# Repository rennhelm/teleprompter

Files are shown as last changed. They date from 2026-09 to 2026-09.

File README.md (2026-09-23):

# Teleprompter

A two-board DIY teleprompter for YouTube and classes: an ESP32-S3 display
board that renders and scrolls the script behind beamsplitter glass, and a
separate ESP32-S3 remote that controls speed, play/pause and re-pacing over
ESP-NOW.

## Repo layout

```
teleprompter/
├── teleprompter-display/   ESP32-S3-Touch-LCD-7B firmware (the actual teleprompter)
├── teleprompter-remote/    ESP32-S3-N16R8 DevKitC firmware (handheld remote)
├── docs/                   Design notes, build history, parts list
└── images/                 Photos / video of the build
```

`teleprompter-display/` and `teleprompter-remote/` are each a complete, independent PlatformIO project
— open either one directly in VS Code (File > Open Folder, the folder
containing its `platformio.ini`) and Build/Upload as normal. See each
project's config header (`src/tp_config.h`, `src/ctl_config.h`) for pins
and tunables.

## What this is

- **Display**: 1024x600 IPS touch display, custom scanline text renderer
  (no frame buffer — see `docs/renderer-rewrite.md`), mirror-flip for
  beamsplitter glass, Wi-Fi AP with a web page to paste/edit the script and
  adjust speed/brightness live, and a "target run length" mode that paces
  the scroll to finish a script in a set time (`docs/pacing-and-run-model.md`).
- **Remote**: three buttons (faster / slower / play-pause), talks to the
  display over ESP-NOW, status LED. See `docs/remote-controller.md`.

## Getting started

1. Read `docs/hardware-gotchas.md` first. It has the known-good
   `platformio.ini` settings and the toolchain fixes (Windows long-path
   limit, wrong PlatformIO platform version) that everything else depends on.
2. Build and flash `teleprompter-display/` first. Join the "Teleprompter"
   Wi-Fi network (password `teleprompter123`) and open `http://192.168.4.1/`
   to confirm the control page loads, before touching the remote.
3. `teleprompter-remote/README.md` covers remote wiring, controls and the
   status LED.

## Parts list

See `docs/Teleprompter_Parts.xlsx`.

## Design background

The `docs/` folder has the fuller story of *why* things are built this way,
including the dead ends (LVGL-based rendering, hardware mirror flip,
on-screen touch controls) so nobody re-walks them:

- `docs/architecture-plan.md` — overall hardware/software decisions and build phases
- `docs/renderer-rewrite.md` — why the display uses a custom scanline renderer instead of LVGL
- `docs/pacing-and-run-model.md` — the target-run-length / start-paused feature
- `docs/remote-controller.md` — remote hardware and the ESP-NOW protocol
- `docs/hardware-gotchas.md` — toolchain and hardware bring-up issues, in the order they were found

## License

See `LICENSE`.

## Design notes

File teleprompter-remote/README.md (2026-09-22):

# Teleprompter remote

ESP32-S3-N16R8 DevKitC, three buttons. Separate PlatformIO project from the
display; flash it to the second board.

## Wiring

Every button is two wires: pin to button, button to GND. Internal pull-ups are
enabled in firmware, so no resistors. Pin numbers live in `src/ctl_config.h`;
if you rewire, change them there and update this table.

| Signal | Pin |
| --- | --- |
| Faster | GPIO7 to GND |
| Slower | GPIO5 to GND |
| Play / pause | GPIO4 to GND |
| LED | GPIO48 (onboard addressable LED on most S3 DevKitC boards) |

Pins avoided on purpose: 0, 45, 46 (strapping), 19, 20 (USB), 26-32 (flash) and
33-37 (the octal PSRAM on an N16R8 part). Nothing here uses the ADC, so the
ADC1-only restriction that an analog control would have imposed does not apply.

## Controls

| Control | Action |
| --- | --- |
| Faster | +5% speed, repeats while held |
| Slower | -5% speed, repeats while held |
| Play | play / pause |
| Play, long (0.8 s) | back to top |
| Faster + Slower together | re-pace: recompute speed to land on the target time |

**Steps are relative, not a fixed px/s.** A "+5 px/s" step would be a 22% change
on a script paced at 23 px/s and a 2% change at 200 px/s, so it would feel
completely different depending on the script. A percentage feels the same
everywhere.

**The change sticks.** Buttons have no spring return, so a speed you press in
stays until you press again. That means the paced speed does drift away from the
target as you use it, which is what the display's drift readout is for, and what
the re-pace chord is for: it recomputes the speed from the distance left over
the time left, putting you back on schedule from wherever you are.

Holding a speed button repeats about six times a second after a half second
delay, so roughly a second of holding is a 1.34x change. Fine adjustment by
tapping, big changes by holding.

## LED

| Colour | Meaning |
| --- | --- |
| Red | no link to the display |
| Amber | paused |
| Green | playing |
| Blue | run finished |
| White flash | command sent |
| Blinking | more than 3 s off the target time |

The blink is the useful one: it tells you to lean on the slower or faster button
without having to look away from the script.

## Setup notes

- `CTL_CHANNEL` must match `TP_AP_CHANNEL` in the display's `tp_config.h`. Both
  are 1. ESP-NOW needs both ends on the same channel and there is no
  negotiation.
- `src/tp_link.h` is a **copy of the display's file**. If you change the
  protocol, copy it across again rather than editing one side.
- Re-pace only does anything when a target length is set on the display. Without
  one there is no schedule to get back onto.

## Tuning the feel

All in `ctl_config.h`:

- `CTL_STEP` (0.05): how much one press moves the speed.
- `CTL_REPEAT_DELAY_MS` (500) and `CTL_REPEAT_MS` (150): how quickly holding a
  button starts and then continues repeating.
- `CTL_LONG_PRESS_MS` (800): how long a hold on Play means back-to-top.

## No link?

The remote prints its MAC and channel at boot, and the display logs
`ESP-NOW listening on channel 1` plus the remote's MAC the first time it hears
from it. If the display never logs the remote, the channel is the first thing to
check. The remote pings once a second when idle, so the display always knows
where to send its status replies even if it reboots mid-session.

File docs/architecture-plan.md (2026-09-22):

# Teleprompter — Hardware Architecture Plan

## Goal
DIY teleprompter for YouTube and classes, built on two ESP32 boards.

## Components
- **Display unit:** Waveshare ESP32-S3-Touch-LCD-7B
  - 1024x600 IPS RGB display, 5-point capacitive touch
  - ESP32-S3, 16MB flash, 8MB PSRAM, dual-core LX7 up to 240MHz
  - Wi-Fi 2.4GHz b/g/n + BLE 5, onboard antennas
  - TF/SD card slot, USB-C (power + flashing), CAN/RS485/I2C headers, PH2.0 LiPo connector
  - Supports Arduino and ESP-IDF
  - Source: https://docs.waveshare.com/ESP32-S3-Touch-LCD-7B
- **Controller unit:** a second, separate ESP32 devkit (e.g. ESP32-C3/S3 mini)
  - Rotary encoder (scroll speed), buttons (play/pause, reverse/restart)
  - Battery powered (single-cell LiPo), handheld/pedal-style remote

## Key architecture decisions
- **Text entry → Wi-Fi**, not Bluetooth. Display board hosts its own small web
  server with a page to type/paste a script directly (originally planned as a
  file upload; switched to an in-browser textarea — simpler, and BLE file
  transfer was impractical for text anyway due to MTU limits).
- **Display Wi-Fi mode → AP (its own hotspot)**, not joining the home LAN.
  This pins the Wi-Fi channel, which avoids channel-sync headaches with
  ESP-NOW (see below). STA + mDNS ("teleprompter.local") can be added later
  once the core works.
- **Scroll control → ESP-NOW**, not classic Wi-Fi or BLE, for the
  controller-to-display link. Peer-to-peer, no pairing ceremony, low enough
  latency that a physical speed knob feels instant. Message = simple struct
  like `{command, value}` (play/pause, speed, reverse).
  **On-screen touchscreen controls were built, tested, then deliberately
  removed** because they competed with the display's own redraw for
  CPU/PSRAM bandwidth. That reason no longer applies under the current
  renderer (see below), but the decision stands on ergonomics: control
  belongs on the wireless remote, not on glass you are reading through.
  Hooks for the remote's receive callback: `tp_display_set_speed(float)` and
  `tp_display_set_paused(bool)`, or `tp_app_set_speed()` /
  `tp_app_set_paused()` / `tp_app_rewind()` to also persist the value and
  reflect it on the web page. Speed is signed, so reverse is a negative
  value with no other change.
  Touch hardware itself is still unused, but the *bring-up* sequence it used
  to perform is load-bearing for the display and is preserved in
  `tp_board_init()` — see hardware-gotchas.md and renderer-rewrite.md.
- **Storage:** LittleFS on the onboard 16MB flash (not the SD card) — the
  current script is saved to `/script.txt` and reloaded on boot. Speed,
  brightness and mirror state live in NVS.
- **Mirror-flip mode is a must-have**, not a nice-to-have — horizontal
  text mirroring is what makes this usable behind teleprompter beamsplitter
  glass. **Resolved in software.** The hardware-level `esp_lcd_panel_mirror()`
  route was a dead end (see hardware-gotchas.md). It is now baked in at
  rasterisation time, once per script, so it costs nothing while scrolling.
- **Rendering → own scanline renderer, not LVGL** (2026-09-14). LVGL remains
  linked only as a font container. See renderer-rewrite.md for the full
  reasoning; the short version is that any design which composes a
  full-screen frame in PSRAM on this board is bandwidth-bound, so the
  firmware composes nothing and generates pixels as they are scanned out.

## Build order (phased)
1. ✅ Bring up display board — flash factory demo, confirm LCD + touch work.
2. ✅ Static renderer — hardcoded text, word wrap, white-on-black, custom
   96pt font.
3. ✅ Mirror-flip.
4. ✅ Auto-scroll engine — smooth, adjustable-speed scrolling.
   **Closed 2026-09-14**: the residual stutter was fixed by replacing the
   renderer outright (renderer-rewrite.md), not by mitigating LVGL. User
   confirmed on hardware that the stutter is gone.
5. ✅ Wi-Fi script entry — AP + web page + textarea + LittleFS save/reload.
   Now applies live; no reboot on save.
6. Controller board — encoder + buttons, ESP-NOW sender. **Not started —
   this is the next milestone.**
7. Pair and tune — connect the two, tune speed mapping/encoder feel, test
   range. Not started.
8. Rig it — mirror glass, mount/stand, battery, enclosure. Not started.

## Current firmware state (display board, as of 2026-09-14)

**Working and confirmed on physical hardware.** Black background, white
word-wrapped text in a custom 96pt Roboto font, optionally mirrored for
beamsplitter glass, auto-scrolling at an adjustable speed, with no stutter.

Rendering is a custom scanline renderer: the RGB panel runs in ESP-IDF's
no-frame-buffer mode and the script is rasterised once into a rolling 4bpp
alpha mask in PSRAM, which the panel's bounce-buffer callback expands
through a lookup table as the pixels are scanned out. Scroll position
advances inside that callback from `esp_timer_get_time()`, so it cannot be
stalled by Wi-Fi, HTTP, flash writes, or anything else running on the chip.
Full reasoning, measurements and verification notes: **renderer-rewrite.md**.

Wi-Fi AP ("Teleprompter" / "teleprompter123") serves a control page at
`http://192.168.4.1/`: script textarea, scroll speed, brightness, mirror
toggle, pause and back-to-top, all applied live.

Project layout:
- `lib/lvgl/` + `lib/lv_conf.h` — LVGL v8.4.0, sibling layout required by
  LVGL's internal includes. Used only for `lv_font_get_glyph_dsc()` and
  `lv_font_get_glyph_bitmap()`; `lv_init()` is never called.
- `src/` — `tp_config.h` (all tunables), `tp_board.cpp` (I2C IO expander:
  backlight, brightness, power-up sequence), `tp_text.cpp` (layout +
  rasterisation), `tp_display.cpp` (panel + scanline renderer + scroll
  clock), `tp_web.cpp` (AP + control page), `main.cpp`, `Roboto_96.c`.
- All Waveshare vendor driver files (`rgb_lcd_port`, `gt911`/`touch`,
  `io_extension`, `i2c`, `esp_lv_adapter_arduino`) have been **deleted**,
  along with all `[DIAG]` instrumentation.

## Headroom now available

Removing the frame buffers freed roughly 2.4 MB of PSRAM (the mask ring uses
2 MB of it), and scanline generation costs about 25% of one core on core 1,
with core 0 essentially idle apart from Wi-Fi. Features that were previously
rejected as too expensive should be re-evaluated against this budget rather
than against the old LVGL numbers.

## Next up
1. **Controller board (Phase 6)**: encoder + buttons, ESP-NOW sender. The
   display-side hooks are already in place (see decisions above).
2. Pair controller with display, tune scroll-speed mapping and encoder
   feel, test range (Phase 7).
3. Recording-workflow polish on the display side — start-paused/lead-in,
   position indicator, adjustable font size. Cheap now; see headroom above.
4. Rig it: mirror glass, mount/stand, battery, enclosure (Phase 8).

## Closed items (do not re-open)
- Scrolling stutter/flicker — closed by the renderer rewrite. The old
  "mitigate or accept the platform quirk" decision in this file is moot.
- `'0'` rendering as `'1'` — an LVGL cmap off-by-one plus a font generated
  without a zero. Fixed in `font_has()` and by regenerating `Roboto_96.c`.
  See renderer-rewrite.md.
- `ESP.restart()` on script save — gone, which also retires the observed
  Octal-PSRAM soft-reset watchdog quirk.

See `hardware-gotchas.md` for the known-good `platformio.ini`, every
toolchain fix, and the detailed history of the mirror-flip, performance,
memory, and backlight/touch-init investigations. See `renderer-rewrite.md`
for the current rendering architecture.

> Note (repo docs pass): this file is the original planning doc and predates
> the remote controller build. It still describes the controller as
> "not started" with an encoder — see `remote-controller.md` for what was
> actually built (three buttons, no encoder). The remote's project folder is
> `teleprompter-remote/`, not `controller/`.

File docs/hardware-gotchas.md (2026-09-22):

# Teleprompter — Hardware Gotchas (ESP32-S3-Touch-LCD-7B)

Hard-won fixes, worth checking before re-diagnosing from scratch.

## UART1 / UART2 switch must match the USB-C port in use
The board has a physical switch selecting between two UART routings (UART1 /
UART2) to the onboard USB-C UART bridge (CH340, appears in Windows Device
Manager as "USB-Enhanced-SERIAL CH340"). If the switch position doesn't match
the port you're actually plugged into, you get a fully-enumerated COM port
that silently fails to talk to the chip — esptool reports:

```
A fatal error occurred: Failed to connect to ESP32-S3: No serial data received.
```

This looks identical to a bad cable, wrong driver, or boot-mode timing issue
(all of which we ruled out first) — check the switch position first.

## Reset button triggers a full POWERON reset, not just a chip reset
Pressing the physical RESET button on this board shows up in the Serial log
as `rst:0x1 (POWERON)` — the *same* reset-reason code as an actual power
cycle — rather than a simple reset-pin toggle (which normally shows up
differently, e.g. `RTC_SW_CPU_RST`). Seeing several `POWERON` resets in a
row during testing does **not** by itself mean the board's power supply is
failing — check whether the reset button was being pressed before chasing a
power-delivery theory (USB cable, port, hub, etc.).

## RTS-based auto-reset after flashing is not fully reliable on this board
esptool reports "Hard resetting via RTS pin..." at the end of a successful
upload. Early on this didn't actually restart the chip into the new firmware
and a manual press of the physical **RESET** button was needed — but this
became unnecessary once we moved to the pioarduino platform / newer esptool
(v5.3.0). If a flash ever seems to succeed but nothing happens on screen or
in the Serial Monitor, press RESET once before assuming something's wrong.

**Also note (2026-09-14):** running PlatformIO's "device monitor" task by
itself does **not** build or flash anything — it only opens the serial port
(which itself reboots the board via DTR/RTS toggling, producing a fresh
`POWERON` boot sequence that can look like a real reflash happened). If a
code change doesn't seem to take effect, confirm the *build/upload* task
actually ran (look for `Compiling ...` and `Writing at 0x...` in the output)
rather than assuming a "monitor" session proves the new code is running.

## Official PlatformIO `espressif32` platform is too old for Waveshare's demo code
Waveshare's example code (in their `ESP32-S3-Touch-LCD-7B` GitHub repo,
`Arduino/examples/` folder) uses `driver/i2c_master.h`, part of ESP-IDF's
newer I2C driver component. The official PlatformIO `espressif32` platform
bundles an older Arduino-ESP32 core that predates this header, causing:

```
fatal error: driver/i2c_master.h: No such file or directory
```

**Fix:** use the **pioarduino** community fork of the platform instead, which
tracks Espressif's current Arduino-ESP32 releases (3.3.x as of this writing,
built on a modern ESP-IDF that includes this driver):

```ini
platform = https://github.com/pioarduino/platform-espressif32/releases/download/stable/platform-espressif32.zip
```

This is a drop-in replacement — same board IDs, same workflow. Switching
platforms triggers a full toolchain re-download (several minutes, not a
hang).

## Windows long paths must be enabled before installing the pioarduino toolchain
The Arduino-ESP32 3.x libs package includes deeply-nested paths (from
Espressif's Matter/connectedhomeip code, for unrelated chip variants) that
exceed Windows' default 260-character path limit, failing with
`WindowsLongPathError`. Fix (one-time, needs a real Administrator PowerShell
— check the title bar literally says "Administrator", not just "run as
administrator" clicked from a non-elevated shell):

```powershell
New-ItemProperty -Path "HKLM:\SYSTEM\CurrentControlSet\Control\FileSystem" -Name "LongPathsEnabled" -Value 1 -PropertyType DWORD -Force
```

Requires a reboot to take effect.

## ESP_LOGI/ESP_LOGW output is silently suppressed by default
Arduino-ESP32's "Core Debug Level" defaults to a level that hides
`ESP_LOGI`/`ESP_LOGW` calls entirely — they just never show up in the Serial
Monitor, with no error. Fix: add `-DCORE_DEBUG_LEVEL=3` to `build_flags`.
Must go in the *same* `build_flags =` block as any other flags — a second,
separate `build_flags =` line causes `InvalidProjectConfError` (duplicate
key).

**Important addendum (2026-09-14) — this fix only works in files that
`#include <Arduino.h>`.** `CORE_DEBUG_LEVEL` only affects `ESP_LOGx` output
in translation units where `Arduino.h` (which pulls in
`esp32-hal-log.h`, the shim that redefines `ESP_LOGx` to route through
Arduino's own formatted logger) is actually included, directly or
transitively. Two of this project's vendor files —
`rgb_lcd_port.cpp` and `esp_lv_adapter_arduino.cpp` — only include raw
ESP-IDF headers and never pull in `Arduino.h`. Their `ESP_LOGx` calls
(including a pre-existing, unconditional `ESP_LOGI(TAG, "Create LVGL
task")` in `esp_lv_adapter_init()` that runs every boot) have **never**
produced any visible Serial output, in any log captured across this whole
project — confirmed to be unrelated to log *level*, since explicitly adding
`esp_log_level_set("*", ESP_LOG_INFO)` as the very first line of `setup()`
(confirmed via the edit shifting `main.cpp`'s own log line numbers by
exactly 1, so the rebuild definitely took effect) still produced zero
output from either file. The actual mechanism wasn't fully pinned down
before this investigation paused, but is most likely a compile-time
`LOG_LOCAL_LEVEL` bound specific to translation units that never see the
Arduino shim, which a runtime `esp_log_level_set()` call cannot override.
**Workaround: use raw `printf()` instead of `ESP_LOGx` when instrumenting
`rgb_lcd_port.cpp` or `esp_lv_adapter_arduino.cpp` (or any other vendor file
that doesn't include `Arduino.h`).** `printf()` writes straight to the
console UART independent of the ESP-IDF/Arduino logging subsystem
entirely, and is confirmed as the reliable way to add diagnostics to these
two files.

## Known-good, confirmed-working `platformio.ini`
```ini
[env:esp32-s3-devkitc-1]
platform = https://github.com/pioarduino/platform-espressif32/releases/download/stable/platform-espressif32.zip
board = esp32-s3-devkitc-1
framework = arduino
monitor_speed = 115200
upload_port = COM4
monitor_port = COM4
upload_speed = 115200
board_build.arduino.memory_type = qio_opi
board_upload.flash_size = 16MB
board_build.partitions = default_16MB.csv
build_flags =
    -DBOARD_HAS_PSRAM
    -DCORE_DEBUG_LEVEL=3
```
(`qio_opi` = Quad I/O flash + Octal I/O PSRAM, correct for this board's
16MB flash / 8MB PSRAM ESP32-S3 module.)

## Display + touch bring-up (Waveshare's own demo, not hand-rolled)
Rather than writing our own RGB-LCD panel init (very finicky — pixel clock,
porches, sync pulses are panel-specific), we're building on top of
Waveshare's own vetted example instead:
- Source: `waveshareteam/ESP32-S3-Touch-LCD-7B` GitHub repo →
  `Arduino/examples/13_lvgl_v8_demo/`
- Driver files (`rgb_lcd_port`, `gt911`/`touch`, `io_extension`, `i2c`,
  `esp_lv_adapter_arduino`) copied into `src/`, left untouched.
- LVGL v8.4.0 + its `lv_conf.h` (from the repo's bundled
  `LVGL_v8.4.0.7z`) copied into `lib/lvgl/` and `lib/lv_conf.h`
  respectively — `lv_conf.h` must sit as a **sibling** of the `lvgl` folder,
  not inside it (LVGL's internal includes expect this relative layout).

**Confirmed working (2026-09-13):** compiled, flashed, and the stock LVGL
widgets demo (`lv_demo_widgets()`) renders on the physical screen with
working touch — full display + touch stack proven before writing any of our
own rendering code.

## RESOLVED: blank screen / no backlight after replacing the demo's setup() (2026-09-14)
**Symptom:** after swapping the stock demo's `setup()`/`loop()` for our own
teleprompter code (Wi-Fi AP, web-based script editor, sliding-window
scrolling canvas), the screen went completely black with **no backlight at
all** — not even a dim glow. This happened on every boot, including a clean
`POWERON` reset with zero errors or crashes in the serial log (confirmed via
diagnostic logging that setup() ran start to finish without issue). Multiple
false leads chased first: a suspected loose FPC ribbon cable (physical
inspection ruled this out), Wi-Fi/AP radio power draw or timing coinciding
with panel init (a real, plausible ESP32-S3 phenomenon, tested by
reordering init and by fully disabling Wi-Fi — screen stayed black either
way, ruling it out), and an unchecked `esp_lv_adapter_lock()` return value
(added logging — the lock was never actually failing).

**Actual root cause, found by diffing our `setup()` against the *original*
working demo's `setup()`:** two real bugs, both in code we hadn't touched
but had never actually run correctly:

1. `wavesahre_rgb_lcd_bl_on()` (in Waveshare's own `rgb_lcd_port.cpp`) is a
   **stub with the real hardware write commented out**:
   ```cpp
   void wavesahre_rgb_lcd_bl_on()
   {
       // IO EXTENSION_io_output(IO EXTENSION_IO_2, 1);  // Backlight ON configuration
   }
   ```
   The commented line doesn't even use real function/identifier names
   (`IO EXTENSION_io_output` isn't a thing — the real function is
   `IO_EXTENSION_Output`). This is a placeholder Waveshare left unfinished in
   their own example. Calling it did nothing.

2. **`touch_gt911_init()` was never called.** The stock demo's `setup()`
   calls it *before* `waveshare_esp32_s3_rgb_lcd_init()`:
   ```cpp
   tp_handle = touch_gt911_init();
   panel_handle = waveshare_esp32_s3_rgb_lcd_init();
   wavesahre_rgb_lcd_bl_on();
   ```
   `touch_gt911_init()` is what actually brings up the I2C bus and the
   IO_EXTENSION GPIO expander chip that the backlight (`IO_EXTENSION_IO_2`),
   touch reset (`IO_EXTENSION_IO_1`), and **LCD reset**
   (`IO_EXTENSION_IO_3`) are all wired through — `EXAMPLE_PIN_NUM_BK_LIGHT`
   is `-1` in `rgb_lcd_port.h` precisely because backlight isn't a direct
   ESP32 GPIO. When we trimmed the demo's `setup()` down for our own use, we
   dropped the touch controller entirely (we don't need touch — see the
   on-screen-controls-removed decision below) and, with it, this
   load-bearing init call. Without it, nothing downstream (backlight, and
   likely the panel's own reset line) ever gets brought out of its power-on
   state, regardless of what the panel/LVGL code does afterward — hence a
   totally clean, crash-free boot with a permanently black screen.

**Fix applied:**
- `waveshare_esp32_s3_rgb_lcd_init()` now calls `DEV_I2C_Init()` (guarded —
  only if the I2C bus isn't already up) and `IO_EXTENSION_Init()` itself, as
  a safety net.
- `wavesahre_rgb_lcd_bl_on()` / `_bl_off()` now actually call
  `IO_EXTENSION_Output(IO_EXTENSION_IO_2, ...)`.
- `setup()` calls `touch_gt911_init()` before
  `waveshare_esp32_s3_rgb_lcd_init()`, exactly matching the proven-working
  demo's order, and passes the resulting `tp_handle` into
  `esp_lv_adapter_init()` instead of `NULL`. We still don't use touch
  functionality (on-screen controls were deliberately removed — see
  architecture-plan.md), but the init call itself is load-bearing for the
  display, not just for touch.

**Lesson for next time:** when a hand-rolled `setup()` diverges from a
vendor demo that's *known* to work on the same hardware, and the failure is
silent (no crash, no error) rather than a crash/assert, diff against the
original demo's init call order line-by-line rather than auditing the new
application logic — the bug can easily be a dropped call that looked
irrelevant (like touch init) rather than anything in the code that was
actually being suspected.

## Mirror-flip: `esp_lcd_panel_mirror()` is a dead end under this board's default render mode
Waveshare's `esp_lv_adapter_arduino` port has three "avoid tearing" modes,
set via `LVGL_PORT_AVOID_TEAR_MODE` in `esp_lv_adapter_arduino.h`:
- Mode 1: double-buffer + full-refresh (redraws the *entire* screen every
  frame)
- Mode 2: triple-buffer + full-refresh
- Mode 3: double-buffer + "direct mode" (**the vendor's default**) — LVGL
  writes straight into the panel's own physical frame buffer

Under mode 3, `esp_lcd_panel_mirror(panel_handle, true, false)` returns
`ESP_OK` but has **no visible effect**, because direct mode bypasses the
`esp_lcd_panel_draw_bitmap()` call where that mirror flag would normally be
honored. Switching to mode 1 does route through that path, but mode 1's
full-screen-every-frame redraw was far too slow on this hardware (PSRAM
bandwidth bound) to be usable. **Don't chase this further** — the working
fix is a software-level pre-mirror instead (next entry), which needs no
render-mode change at all.

## Mirror-flip: working approach — pre-mirror once into an off-screen canvas
Render the script text once into an `lv_canvas` (an off-screen pixel
buffer), flip that buffer's pixels horizontally exactly once (for a
`LV_IMG_CF_TRUE_COLOR` buffer this is a simple per-row swap:
`row[x] ↔ row[w-1-x]`), then scroll the canvas object like any normal
widget. Because the mirror only runs once at creation/refill time — never
per animation frame — it costs nothing while scrolling. Any buttons/sliders
should stay as separate, non-canvas objects so they render normally
(correct, since those are read directly, not through the beamsplitter
glass).

## `lv_canvas` buffer-size macros: use LVGL's own macro, don't hand-compute the stride
Learned the hard way, twice, while trying a memory-saving 1-bit format:
`LV_CANVAS_BUF_SIZE_ALPHA_1BIT(w, h)` (and the sibling indexed/alpha macros)
use a row stride of `(w >> 3) + 1` bytes — **not** the more "obvious"
`(w + 7) / 8`. Getting this wrong causes silently corrupted/blank canvas
content with **no crash**, and a related second bug: if a hand-rolled
scratch buffer for mirroring is sized off the wrong (smaller) stride, it
overflows and triggers `Stack smashing protect failure!` on return. Always
pull the real per-row size from LVGL's own macro and size any scratch
buffers from that same number. (`LV_IMG_CF_TRUE_COLOR` has no such trap —
its stride is just `w * sizeof(pixel)`.)

## `LV_IMG_CF_ALPHA_1BIT` + `img_recolor` styling: tried, abandoned as unreliable
To fit a long script's rendered image into available PSRAM, tried switching
the mirror canvas from full RGB565 color (2 bytes/pixel) to a 1-bit alpha
mask (16x smaller) plus `lv_obj_set_style_img_recolor()` /
`_recolor_opa()` to paint the mask white. After fixing the stride bug above,
it stopped crashing, but **never actually rendered any visible content** —
confirmed via a pixel-count diagnostic that the buffer genuinely contained
correctly-drawn glyph data, yet nothing appeared on screen. Root cause not
found. **Went back to `LV_IMG_CF_TRUE_COLOR`** (the format proven to work)
and solved the memory problem a different way instead (next entry) rather
than continuing to debug this blind.

## Long-script memory problem: use a small sliding window, not one giant pre-rendered image
Pre-rendering the *entire* script as one full-color image doesn't scale — a
590-byte test script alone wraps to ~2987px tall, needing ~5.8MB as a
`LV_IMG_CF_TRUE_COLOR` canvas, more than the ~4.4MB of PSRAM actually free
after the display's own frame buffers and other allocations. A real script
would only be worse.

**Fix:** allocate one small, **fixed-size** canvas (2 screen-heights tall —
independent of script length) and treat it as a window sliding through the
full script's virtual height. The key trick: `lv_canvas_draw_text()` will
happily draw starting from a *negative* Y coordinate and clip everything
above the canvas automatically, so "render the slice starting N pixels into
the document" is just `lv_canvas_draw_text(canvas, 0, -N, ..., full_script)`
— no manual line-break/pagination bookkeeping needed, LVGL's own word-wrap
does it every time. Refill (clear, redraw, re-mirror) only when the visible
viewport gets within one screen-height of the edge of what's currently
rendered — at typical scroll speeds that's roughly once every several
seconds, cheap enough not to affect frame rate.

Status: position math and buffer content both verified correct via
diagnostic logging, and — as of the backlight/touch-init fix above — now
confirmed actually rendering on the physical display too.

### Useful diagnostic pattern for "is it a position bug or a content bug?"
When something won't show up on screen, add periodic logging of the actual
state (`lv_obj_get_y()`, a manual pixel-count scan of the canvas buffer for
non-zero values) rather than re-reading the code blind. This cleanly
separated "the scroll math is right and the buffer genuinely has drawn
content in it" from "but nothing reaches the physical screen" in one round,
instead of several more rounds of guessing.

## RESOLVED (root cause identified 2026-09-14): scrolling flicker/choppiness — LVGL's own render+flush cost climbs to ~300ms+ under continuous scrolling

**Symptom:** user-reported "flicker, makes it hard to read" while scrolling.

**Real fixes made along the way (confirmed via log evidence, worth keeping
regardless of the root-cause finding below):**
1. `lv_canvas_fill_bg()` cost ~768,000us per call. Replaced with a direct
   `memset()` (fill color is always solid black = all-zero bytes on
   RGB565) — now ~207,000-320,000us, matching a raw PSRAM memset benchmark
   of the same buffer size. The remaining cost is genuine PSRAM bus
   contention from the RGB panel's continuous framebuffer DMA (confirmed
   via an early pre-panel-init vs. post-panel-init memset benchmark showing
   a 3-4.4x slowdown once the panel starts driving the display), not
   further software inefficiency.
2. `g_window_height` was `screen_height * 2`, which worked out to *zero*
   effective refill margin (the trigger math landed exactly at the
   threshold), causing back-to-back refills instead of the intended ~8s
   spacing. Changed to `* 3`; log-confirmed refill spacing now matches
   predicted math for the test script.
3. `scroll_timer_cb()` originally advanced the scroll position by a
   **fixed** per-tick amount regardless of actual elapsed time — silently
   cutting the real average scroll speed to roughly 1/10th of the
   configured px/sec once it became clear ticks were actually arriving
   every ~300ms+ instead of the intended ~33ms. Fixed to scale the step by
   real elapsed time (`gap_ms`) instead of assuming a fixed period.
4. Added a guard to skip a wasted "refill an already-blank window" event
   that happened right before wrap-to-top, when the test script (1066px)
   was shorter than the (now larger) render window (1800px). **Not yet
   independently re-verified with a dedicated log** — present in the
   flashed firmware but its effect hasn't specifically been confirmed.

**Diagnostic method:** added `g_max_tick_gap_ms` to `main.cpp` (actual
elapsed time between `scroll_timer_cb()` firings, via `millis()`), which
consistently settled around ~306-320ms during normal scrolling (vs. the
intended ~33ms), with spikes to ~950-1040ms lining up with
`refill_window()` calls. To find out *why*, added `printf()`-based
instrumentation (see the `ESP_LOGI/ESP_LOGW` gotcha above for why `printf`
and not `ESP_LOGx`) directly inside the vendor `esp_lv_adapter_arduino.cpp`,
measuring three things separately: (a) `flush_callback()`'s
`ulTaskNotifyTake()` vsync-wait time, (b) `lv_timer_handler()`'s own total
execution time per call, and (c) the full `lvgl_port_task` loop iteration
time.

**Findings, definitive:**
- **Ruled out: Wi-Fi/AP/webserver polling.** Direct paired A/B test
  (`ENABLE_WIFI=1` vs. `0`) showed statistically identical
  `max_tick_gap_ms` in both; only `free_heap` differed.
- **Ruled out: the RGB panel's own vsync timing, and the `flush_callback()`
  blocking-wait theory.** The instrumented vsync wait stayed a steady
  ~23-30ms throughout, matching the calculated panel refresh rate
  (`EXAMPLE_LCD_PIXEL_CLOCK_HZ` + porch/pulse-width constants ≈ 32.75Hz ≈
  30.5ms/frame) almost exactly. This is the *opposite* of the ~300ms
  anomaly, so the flush-blocking mechanism is not the cause.
- **Ruled out: task-scheduling/`vTaskDelay` slippage.** `task_delay_ms`
  (what `lv_timer_handler()` asks the task to sleep) was always `0`
  (clamped up to the 10ms floor) — the loop is not waiting on anything
  external to `lv_timer_handler()` itself.
- **Confirmed root cause: `lv_timer_handler()`'s own execution time climbs
  over time, independent of refills, until it plateaus around the observed
  ~295-320ms** — e.g. one capture showed it climb steadily across roughly
  10-15 seconds (119ms → 173ms → 234ms → 295ms) then hold there, tracking
  `max_tick_gap_ms` almost exactly. This is the actual rendering/flush cost
  of moving our canvas each tick — not a blocked wait, not a scheduling
  gap, just genuinely slow.

**This is almost certainly the same phenomenon as the "periodic ~2-minute
redraw slowdown" entry above** (a documented, unresolved community report —
suspected PSRAM cache-coherency mismatch between the Arduino-ESP32 core and
Octal PSRAM burst behavior), just captured here with much finer
granularity via direct instrumentation rather than coarse tick-interval
sampling. Both entries should be read together; they're very likely one
underlying platform limitation, not two separate bugs. See the same two
reference links there.

**Practical takeaway:** the ~300ms+ stall is not fixable by anything in our
own `main.cpp` scroll/render logic (already-fixed items 1-4 above were
worthwhile independently, but don't touch this), and multiple external
reports treat the underlying cause as an unresolved platform/core
limitation rather than something fixable from application code. **Decision
point, not yet made:** whether to (a) look for an application-level
mitigation that reduces how much area gets re-flushed per tick (e.g.
smaller per-tick invalidation), accepting this is a mitigation and not a
fix, or (b) accept this as a documented platform quirk, same as the
2-minute-oscillation entry above, and move on to the remaining build
phases (controller board, ESP-NOW, enclosure). Revisit this decision before
doing any further internals-level work here — don't restart the
investigation from scratch.

**Diagnostics left in place:** `main.cpp` still has
`g_max_tick_gap_ms`/`diagnostics_timer_cb()`, and
`esp_lv_adapter_arduino.cpp` still has the `printf()`-based `[DIAG]`
instrumentation described above (three checkpoints: entry of
`esp_lv_adapter_init()`, entry of `lvgl_port_task()`'s loop, and a
100-iteration heartbeat plus new-max-only prints for the three measured
timings). Safe to leave in — cheap when nothing new happens — but worth
removing once this is fully closed out, since the `[DIAG]`-prefixed lines
add serial noise.

## Possible ESP32-S3 Octal-PSRAM soft-reset quirk after Wi-Fi save-and-restart (watch for recurrence)
While diagnosing the blank-screen issue above, one boot (following the
web UI's "Save and Restart", which calls `ESP.restart()` right after a
PSRAM-heavy canvas allocation) came up with `rst:0x10 (RTCWDT_RTC_RST)` — a
watchdog reset — and hung right after the "Script wraps..." log line before
finishing setup. This didn't reproduce on every save+restart cycle, so it
wasn't chased further, but it matches a known ESP32-S3 erratum where Octal
PSRAM doesn't always reinitialize cleanly after a *soft* reset
(`esp_restart()`), only after a real power cycle. If this recurs
consistently, the fix is likely avoiding `ESP.restart()` after heavy PSRAM
use (or forcing a harder reset), not a code bug in our sketch.

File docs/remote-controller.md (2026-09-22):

# Teleprompter — Remote controller (Phase 6, 2026-09-15)

Second board: ESP32-S3-N16R8 DevKitC. **Three buttons**: faster, slower,
play/pause. Separate PlatformIO project in `teleprompter-remote/` (earlier planning
notes called it `controller/`).

A joystick version was built first and then dropped in favour of buttons. The
reasoning behind both is kept below, because the shape of the control determines
the command it should send and that is not obvious.

## The control shape decides the command

The protocol carries two ways to move the speed. Which one is correct depends
entirely on whether the control springs back by itself.

**Buttons → `TP_CMD_SPEED_NUDGE`** (what is built). Scales the base speed by a
relative amount, and the change **sticks**:

```
base *= (1 + value / 1000)
```

Relative, not absolute, on purpose: a fixed "+5 px/s" step is a 22% change at
23 px/s and a 2% change at 200 px/s, so it would feel completely different
depending on the script length. A percentage feels the same everywhere.

Because the change sticks, the paced speed does drift away from the target as
you use it. That is what the drift readout is for, and what re-pace is for.

**Spring-centred controls (joystick, slider) → `TP_CMD_SPEED_TRIM`** (in the
protocol, unused by this remote). Biases the base speed rather than replacing
it, `effective = base * (1 + trim)`, so letting go returns the scroll to exactly
the paced speed and the target can never be lost. A momentary trim also needs
the display-side failsafe that clears it if the remote goes quiet, so a flat
battery mid-deflection cannot leave the scroll stuck fast. That failsafe only
arms when a non-zero trim arrives, so the button remote never triggers it.

Base speed and trim stay separate variables on the display (`s_speed`, `s_trim`)
composed in one place (`apply_speed()` in `main.cpp`), so the web slider, the
duration target and the remote never fight over one value. `tp_app_repace()`
zeroes the trim, because "put me back on schedule" means from neutral.

## Control layout

| Control | Action |
| --- | --- |
| Faster (GPIO7) | +5%, repeats while held |
| Slower (GPIO5) | -5%, repeats while held |
| Play (GPIO4) | play / pause |
| Play, long 0.8 s | back to top |
| Faster + Slower together | re-pace |

The chord saves a fourth button for what is genuinely the most useful mid-take
control. One stray nudge fires before the chord is detected; harmless, because
re-pace recomputes the speed outright. Both buttons are then suppressed until
released so the chord does not ripple the speed.

All three buttons are pin-to-GND with internal pull-ups. **Nothing uses the ADC,
so the ADC1-only constraint below does not apply to the built remote.**

LED (onboard addressable, GPIO48): red = no link, amber = paused, green =
playing, blue = finished, white flash = command sent, blinking = more than 3 s
off the target. The blink is the useful one; it prompts a correction without
looking away from the script.

## Kept for reference: the ADC gotcha, if an analog control is ever added

An analog joystick or slider **must** be on ADC1, GPIO1-10. ADC2 shares hardware
with the Wi-Fi radio and reads on it fail whenever the radio is active, which on
this remote is always. It presents as a broken control, not as an error. Also:
VCC to 3V3, not 5V, or the ADC clips; and calibrate centre at boot by averaging,
because no real thumbstick sits at 2048.

Pins avoided throughout: 0/45/46 (strapping), 19/20 (USB), 26-32 (flash), 33-37
(octal PSRAM on an N16R8 part).

## Link details

- `CTL_CHANNEL` must equal `TP_AP_CHANNEL` (both 1). ESP-NOW has no channel
  negotiation, which is why the display's soft AP is pinned.
- The remote broadcasts; the display replies to whoever sent the command. The
  remote pings once a second when idle so the display always knows where to
  send status, even if the display reboots mid-session.
- `teleprompter-remote/src/tp_link.h` is a **copy** of the display's. Change one, copy it
  across; never edit one side only.
- Received commands are queued and applied on the display's own task, not in the
  Wi-Fi callback, because a rewind re-rasterises and would stall the Wi-Fi stack
  for a couple of hundred milliseconds.

## Also changed on the display side

- `tp_app_nudge_speed(factor)` added, floored at `TP_PACE_SPEED_MIN` rather than
  the slider's minimum, so a legitimately slow paced speed does not jump when
  nudged.
- `tp_app_set_speed()` and `tp_app_set_brightness()` no longer write NVS
  immediately; a repeating button would hammer flash. Flushed from `loop()` once
  settled.
- Status frames report the **effective** speed and compute drift from it.
- Web page shows "remote trim +25%" when a trim is applied, and uses the
  effective speed for its projections.

## Verification status

The button state machine was simulated on the host across five scenarios: a tap
gives exactly one step; a 1.2 s hold gives six steps (1.34x, matching the
documented figure); the chord gives one stray nudge then re-pace and nothing
further until release; a play tap gives only a toggle; a long play hold gives
only a rewind and no toggle on release. ESP-NOW callback signatures were checked
against `esp_now.h` for IDF 5.5 (note `esp_now_send_cb_t` changed shape in 5.4,
so no send callback is registered).

**Neither the remote firmware nor the display's nudge path has run on
hardware.** First check: the remote prints its MAC and channel at boot, and the
display logs the remote's MAC the first time it hears from it. If that line
never appears, check the channel.

> Note: this file is the design record. For current wiring and day-to-day use,
> `teleprompter-remote/README.md` is the operational reference, and
> `teleprompter-remote/src/ctl_config.h` is the source of truth for pins.

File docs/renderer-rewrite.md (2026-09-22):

# Teleprompter — Renderer rewrite (2026-09-14)

Closes the open decision in architecture-plan.md ("pursue an application-level
mitigation, or accept the ~300ms LVGL stall as a platform quirk"). **Neither.**
The third option was taking LVGL out of the render path entirely.

## Why the old approach could not be tuned into working

The earlier investigation was correct that `lv_timer_handler()` cost climbed to a
~300ms plateau, and correct that it wasn't vsync, Wi-Fi or scheduling. The
missing piece is *why* that ceiling exists, and it isn't a cache-coherency
erratum — it's arithmetic:

- The panel's own refresh DMA reads the 1.2 MB PSRAM frame buffer continuously,
  ~40 MB/s, whether or not anything changes. (With `bounce_buffer_size_px` set,
  that read is done by a CPU `memcpy` inside the DMA ISR, ~1960 interrupts/sec.)
- Scrolling a canvas means most of the screen is dirty every frame, so LVGL must
  re-blit ~614k pixels through its draw pipeline into PSRAM.
- ESP32-S3 PSRAM writes go through a **write-allocate** cache, so writing a frame
  costs a read *and* a write — roughly 2.4 MB of bus traffic per frame on top of
  the panel's own 40 MB/s.

Any design that composes a full-screen frame in PSRAM is bandwidth-bound on this
board. That is why mode 1 (full-refresh) was "too slow", why `lv_canvas_fill_bg`
was 768 ms, and why the raw `memset` benchmark only reached ~12 MB/s.

## What replaced it: generate scanlines, keep no frame buffer

The RGB panel now runs in ESP-IDF's no-frame-buffer mode
(`esp_lcd_rgb_panel_config_t.flags.no_fb = 1`, which **requires `num_fbs == 0`**).
In that mode the driver calls `on_bounce_empty(panel, buf, pos_px, len_bytes, ctx)`
to have the application fill each bounce buffer just before it is shifted out.

1. The script is rasterised **once** into a rolling 4-bits-per-pixel alpha mask in
   PSRAM (`TP_RING_ROWS` = 4096 rows x 512 bytes = 2 MB). Mirroring is baked in at
   rasterisation, never per frame.
2. The callback expands the 12 scanlines it is about to send straight from that
   mask through a 256-entry lookup table: one lookup and one aligned 32-bit store
   per two pixels.
3. Scroll position advances inside that callback from `esp_timer_get_time()`, in
   integer fixed point (no FPU in an ISR), latched once per frame at `pos_px == 0`.

Results by construction, not by tuning:
- PSRAM traffic per frame: ~2.4 MB → ~300 KB (mask reads only). Pixels are built
  in internal SRAM.
- Per-frame cost is **constant** — there is no periodic refill left to hitch on.
- Scrolling cannot be stalled by software. Wi-Fi, HTTP, flash writes and
  rasterising the next line all sit outside the render path.
- No tearing: pixels are generated as they are scanned out.
- Budget: ~1.8M cycles/frame of scanline generation ≈ 25% of one core, on core 1.
  Wi-Fi and the web server on core 0.

Fallback if `no_fb` ever misbehaves: `TP_USE_FRAMEBUFFER 1` in `tp_config.h`
switches to two PSRAM frame buffers filled by the same row-expansion code. Much
slower (~10-15 fps), but conventional, so it is a useful A/B.

## Silent bug found: LVGL resolves the codepoint just past a cmap range

`lv_font_get_glyph_dsc_id()` in LVGL 8 tests `rcp > range_length` rather than
`>=`. The single codepoint immediately after each cmap is therefore reported as
present and resolved to the **first glyph of the next range**.

`Roboto_96.c` was generated with `--symbols ...123456789...` — no `'0'` — and its
two ranges are 0x20-0x2F and 0x31-0x7E. So `'0'` (0x30) resolved to `'1'`:
**"2026" was rendering on screen as "2126"**, and every price and time was wrong,
with no error anywhere. Verified by host-rendering the real font.

Two fixes, both applied:
- `font_has()` in `tp_text.cpp` walks the cmaps itself, so a character the font
  lacks is always treated as missing rather than drawn as its neighbour.
- `src/Roboto_96.c` regenerated over 0x20-0x7E plus en/em dash, curly quotes and
  ellipsis, from the same Roboto variable font. Metrics are identical
  (`line_height` 103, `base_line` 23), and the `__has_include` header block is
  reproduced. To regenerate (e.g. a different size or typeface), with
  [lv_font_conv](https://github.com/lvgl/lv_font_conv) and a Roboto `.ttf`:

  ```
  npx lv_font_conv --bpp 4 --size 96 --no-compress --font roboto.ttf \
    -r 0x20-0x7E -r 0x2013-0x2014 -r 0x2018-0x2019 -r 0x201C-0x201D -r 0x2026 \
    --format lvgl -o src/Roboto_96.c
  ```

  Keep `0x20-0x7E` as one unbroken range. A gap is what caused the `'0'` bug.

## Gotchas from hardware-gotchas.md that are honoured in the new code

- **`ESP_LOGx` needs `Arduino.h` in the translation unit.** Every new source file
  includes it first, deliberately, with a comment saying why. Logging is visible
  this time; no `printf` workaround needed.
- **`touch_gt911_init()` was load-bearing for the display, not for touch.**
  `touch_gt911_init()` is gone, but `tp_board_init()` runs the same sequence in
  the same order before the panel: I2C up, expander mode register to all-outputs,
  then the GPIO4 / expander-IO1 reset dance with the same delays. LCD reset (IO3)
  high; backlight (IO2) explicitly low until 120 ms after the panel is scanning,
  so there is no garbage flash at boot. `tp_board_backlight()` really writes to
  the expander — it is not the vendor's commented-out stub.
- **`lib/lvgl/` + `lib/lv_conf.h` sibling layout** is unchanged. LVGL is now only
  a font container (`lv_font_get_glyph_dsc` / `lv_font_get_glyph_bitmap`).
  Nothing calls `lv_init()`, so its 48 KB pool is never allocated.
- **The Octal-PSRAM soft-reset quirk** can no longer be hit in normal use: saving
  a script re-lays out in place instead of calling `ESP.restart()`.
- Waveshare driver files deleted: `esp_lv_adapter_arduino.*`, `rgb_lcd_port.*`,
  `gt911.*`, `touch.*`, `i2c.*`, `io_extension.*`, along with all `[DIAG]`
  instrumentation.

## ESP-NOW hooks (Phase 6) are intact

`tp_display_set_speed(float)` and `tp_display_set_paused(bool)` are what the
remote's receive callback should call; `tp_app_set_speed()` / `tp_app_set_paused()`
/ `tp_app_rewind()` additionally persist and reflect on the web page. Speed is
signed, so reverse is a negative value with no other change. Wi-Fi stays in AP
mode, so the ESP-NOW channel is still pinned.

## Verification status

Host-compiled and rendered against real LVGL 8.4 font code and the actual font:
layout, word wrap, mid-word breaking, blank lines, glyph placement,
anti-aliasing, 4bpp mask packing, mirroring and the lookup-table expansion were
all checked as images. The ESP-IDF panel configuration was checked against
`esp_lcd_panel_rgb.h` / `.c` for IDF 5.5 (what pioarduino pulls in), in
particular that `no_fb` requires `num_fbs == 0`, that the frame-buffer size must
be a whole multiple of the bounce-buffer size (so `TP_BOUNCE_LINES` must divide
600), and the `on_bounce_empty` signature.

**Not yet flashed or run on the board.** First log lines to check:

```
I tp_display: scanline renderer active: no frame buffer, 12-line bounce buffers
I tp_text: laid out N lines, 115 px per line, ... rows per pass
I teleprompter: 32 fps | row ... | heap ... | psram ...
```

A steady ~32 fps with the row number climbing evenly is the fix working.
If bands of the screen tear or repeat under heavy Wi-Fi load, raise
`TP_BOUNCE_LINES` to 20 (costs 80 KB of internal RAM instead of 48 KB).

> Note (repo docs pass): "not yet flashed" above is as of this doc's original
> date (2026-09-14); architecture-plan.md's later changelog says the stutter
> fix was confirmed on hardware. Treat the verification note as historical.

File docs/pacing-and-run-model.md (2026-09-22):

# Teleprompter — Run model: target length and start-paused (2026-09-14)

Adds "set a target length and the script finishes in that time", plus booting
paused. Builds on the scanline renderer (see renderer-rewrite.md).

## The run model, and why the definition matters

A **run** is defined as: *first line sitting on the reading row* → *last line
sitting on the reading row*. The reading row is `TP_READ_LINE_Y` in
`tp_config.h`, default `V_RES / 3` = 200 px.

The useful consequence: the distance covered is exactly

```
travel = text_rows - line_height
```

which is **independent of where the reading row sits**. Moving the reading row
changes where the text rests on screen, not the timing. So:

```
speed_px_per_sec = travel / target_seconds
```

is the whole calculation. The start position is `-TP_READ_LINE_Y` (negative, so
there is blank above line one); `tp_text_row_ptr()` already returns null for
negative rows, so no special case was needed.

Any other definition of "finished" is materially wrong. If the run ended when
the last line scrolled off the *top*, the target would be overshot by one screen
height of travel — about 20% of a two minute run on a typical script — because
the speaker stops talking a screen-height before the text stops moving.

### Verified on host

`/tmp` harness rendered the frames at both extremes against the real font:
at the start position line one sits on the reading row with blank above; at the
end position the final line sits on that same row, earlier lines visible above
it for context, and **zero ink below it**. Numbers from the check: 25 lines,
69 words, text 2875 rows, travel 2760, so 2:00 → 23.0 px/s.

## Deliberately open loop

The target sets the **initial speed only**. The slider and the ESP-NOW hooks
still move it freely afterwards. There is no continuous auto-correction, on
purpose: a speed that creeps around while you are reading is horrible to read
from. Instead the control page shows the consequences and offers a manual fix:

- run clock `0:47 / 2:00`
- what the current speed projects to, and time left
- drift, "0:03 ahead" / "0:03 behind", once you have nudged the speed
- words per minute, flagged amber above 200 — the real sanity check, since a
  two minute target on a long script may imply an impossible reading rate
- **Re-pace**: recompute speed from distance left over time left

If continuous auto-pacing is ever wanted, it belongs behind a flag, not as the
default.

## Start paused, stop at end

- `TP_START_PAUSED` (default 1): boots parked with line one on the reading row.
  `s_paused` is initialised to this at file scope in `tp_display.cpp`, so there
  is no window between panel init and the first `set_paused()` call.
- `TP_STOP_AT_END` (default 1): the renderer pauses and latches `finished` when
  it reaches `end_row`, instead of looping. Reversing past `start_row` also
  stops. Set both to 0 for a continuously looping display.
- "Back to top" parks paused too — a rewind means "getting ready for a take".
- Play on a finished run rewinds first, and the page's button reads "Restart".

## Implementation notes

- **Run clock lives in the frame callback**, accumulated from the same `dt` the
  scroll position uses, so it measures scrolling rather than wall time and stops
  cleanly when paused. Kept as a 32-bit millisecond counter specifically so a
  task can read it without tearing against the interrupt that writes it (a
  64-bit microsecond counter could not be read atomically).
- **`apply_pacing()` is re-run on every layout change** — new script, mirror
  toggle — which is the real value of the feature: paste a longer script and the
  target holds, the scroll just slows down.
- `reload()` rewinds *before* re-laying out so the mask top-up task is not
  chasing a target derived from the old script, then rewinds again once the new
  range is known.
- Word count is a separate byte-wise pass (UTF-8 continuation bytes are all
  >= 0x80, so they can never be mistaken for whitespace). The layout loop itself
  rescans characters on line breaks, so counting inside it would double-count.
- New API: `tp_display_set_range()`, `tp_display_start_row()`,
  `tp_display_end_row()`, `tp_display_finished()`, `tp_display_run_ms()`,
  `tp_text_rows()`, `tp_text_word_count()`, `tp_app_set_duration()`,
  `tp_app_repace()`.
- NVS key `duration` (seconds, 0 = off) alongside `speed`, `mirror`, `bright`.

## Control page verified in a browser

The page was rendered headless against mock state at 400 px and 760 px wide:
no JS errors, and the arithmetic checked by hand against the mock (0:47 of 2:00,
1:16 left, 3 s behind, 35 wpm, progress bar at 37%). The firmware side of this
change has **not** been run on the board.

## Note for the ESP-NOW remote (Phase 6)

The run model gives the remote more to work with than play/pause/speed:
`tp_display_finished()` and `tp_display_run_ms()` are worth surfacing on the
handheld, and `tp_app_repace()` is a good candidate for a physical button —
"put me back on schedule" is a more useful control mid-take than nudging speed
by hand.

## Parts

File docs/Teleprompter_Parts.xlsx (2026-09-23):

Part | Price | Unit Price | DigiKey # | Qty. | Link
Waveshare ESP32-S3-Touch-LCD-7B | $54.99 | $54.99 | - | 1 | Link (https://www.amazon.com/dp/B0FDQXKFJ5?ref=ppx_yo2ov_dt_b_fed_asin_title)
ESP32-S3-N16R8 | $18.99 | $6.33 | - | 1 | Link (https://www.amazon.com/dp/B0F5QCK6X5?ref=ppx_yo2ov_dt_b_fed_asin_title&th=1)
Tactile Buttons (6X6X8) | $8.99 | $0.05 | - | 3 | Link (https://www.amazon.com/dp/B07ZBHXBZ4?ref=ppx_yo2ov_dt_b_fed_asin_title)
2.54mm Female Pin Connector (1X6) | $12.95 | $0.10 | - | 4 | Link (https://www.amazon.com/dp/B0GLHJ3DXH?ref=ppx_yo2ov_dt_b_fed_asin_title)
22 AWG Solid Core Tinned Copper Wire | $16.19 | $16.19 | - | 1 | Link (https://www.amazon.com/dp/B07TX6BX47?ref=ppx_yo2ov_dt_b_fed_asin_title&th=1)
Pololu S7V8F3 | $9.95 | $9.95 | 2183-2122-ND | 1 | Link (https://www.digikey.com/en/products/detail/pololu/2122/10451140?s=N4IgTCBcDaIAoHsA2yCuACMBGMEC6AvkA)
PCB Prototype Board | $7.99 | $0.25 | - | 2 | Link (https://www.amazon.com/dp/B0DBZ1BXFZ?ref=ppx_yo2ov_dt_b_fed_asin_title)
3.7V 103450 LiPo Battery 2000mAh | $8.99 | $8.99 | - | 1 | Link (https://www.amazon.com/dp/B0GDQVRHHZ?ref=ppx_yo2ov_dt_b_fed_asin_title&th=1)
TP4056 USB-C Charger Module | $5.99 | $2.00 | - | 1 | Link (https://www.amazon.com/dp/B07PKND8KG?ref=ppx_yo2ov_dt_b_fed_asin_title)
3D Printer Filament - PLA | $23.73 | $23.73 | - | 1 | Link (https://www.amazon.com/ELEGOO-Filament-Dimensional-Accuracy-Cardboard/dp/B0BM7465PB)
Adult Crew T-Shirt | $5.19 | $5.19 | - | 1 | Link (https://www.hobbylobby.com/clothes-accessories/blank-shirts-hoodies/black---adult-crew-t-shirt---2xl/p/27990)

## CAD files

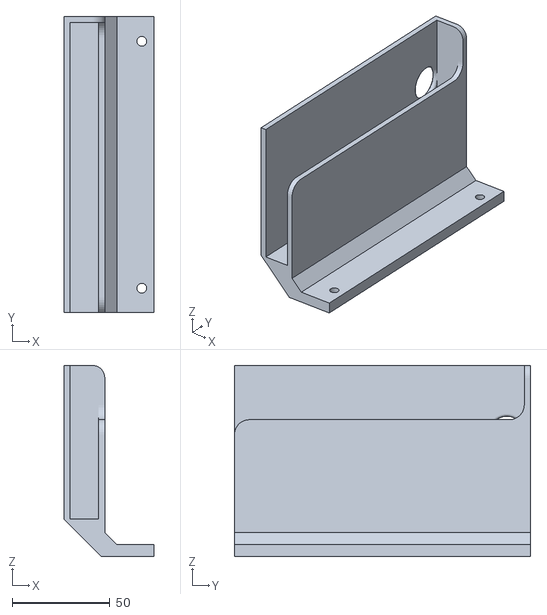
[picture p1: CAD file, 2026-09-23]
teleprompter-stls/Teleprompter_Phone_Mount.stl
46.2 x 151.5 x 97.9

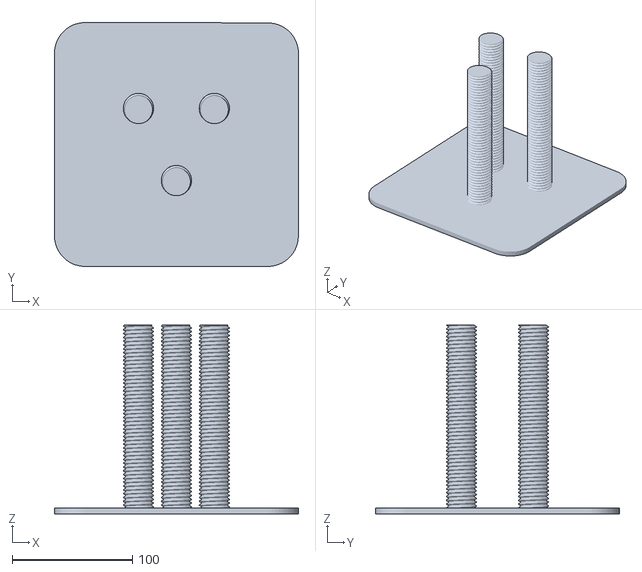
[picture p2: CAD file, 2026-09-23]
teleprompter-stls/Teleprompter_Stand_Bottom.stl
203.3 x 203.2 x 157.5

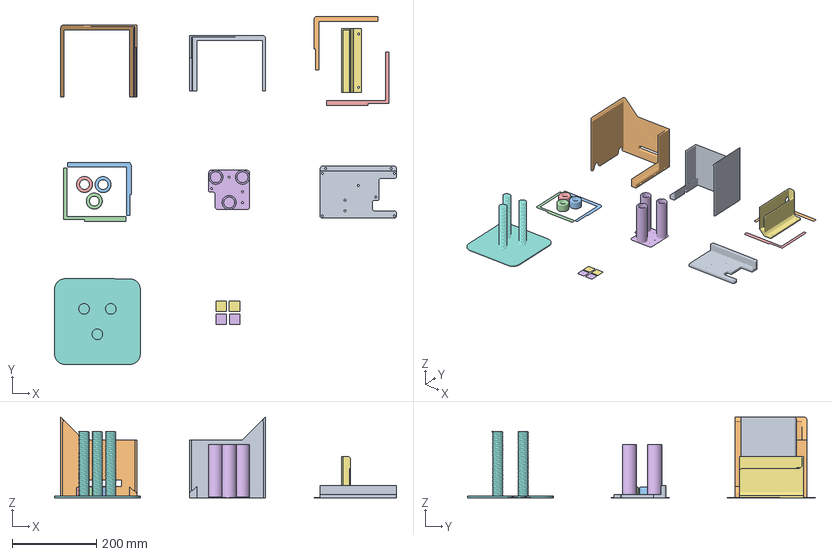
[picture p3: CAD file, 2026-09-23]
teleprompter-stls/Teleprompter.3mf
809.6 x 823.9 x 191.4 mm
Mounting_Bracket.stl
Teleprompter_Glass_Holder.stl x 4
Teleprompter_Stand_Top.stl
Teleprompter_Phone_Mount.stl
Teleprompter_Stand_Bottom.stl
Teleprompter_Hood.stl x 2
Teleprompter_Stand_Adjuster.stl x 3
Teleprompter_Cloth_Holder.stl x 2

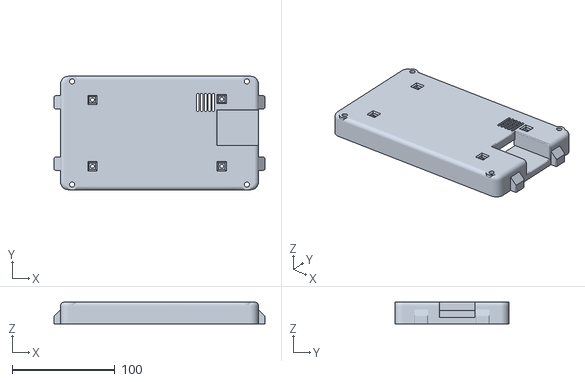
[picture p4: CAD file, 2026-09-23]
teleprompter-stls/ESP32-S3-Touch_Case.stl
205.7 x 110.7 x 21.3

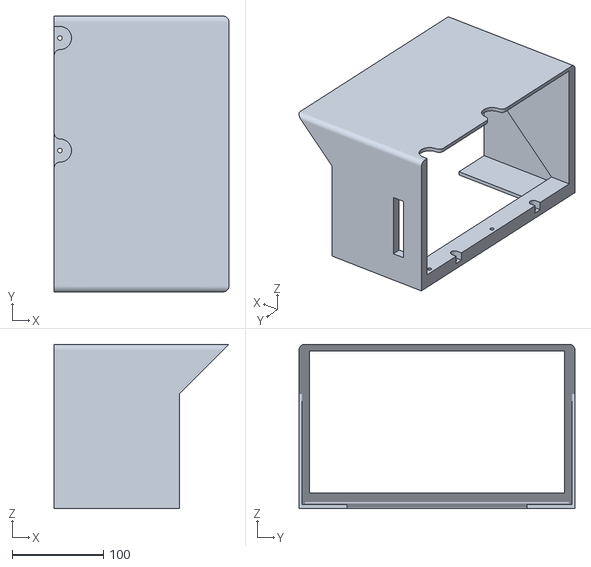
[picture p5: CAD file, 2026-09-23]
teleprompter-stls/Teleprompter_Hood.stl
191.4 x 302.3 x 180.0

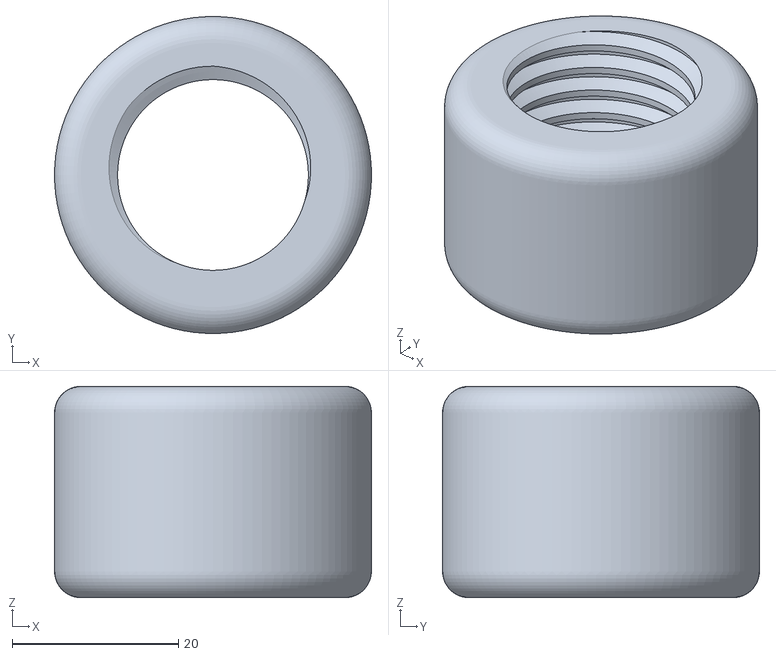
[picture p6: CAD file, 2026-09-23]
teleprompter-stls/Teleprompter_Stand_Adjuster.stl
38.1 x 38.1 x 25.4

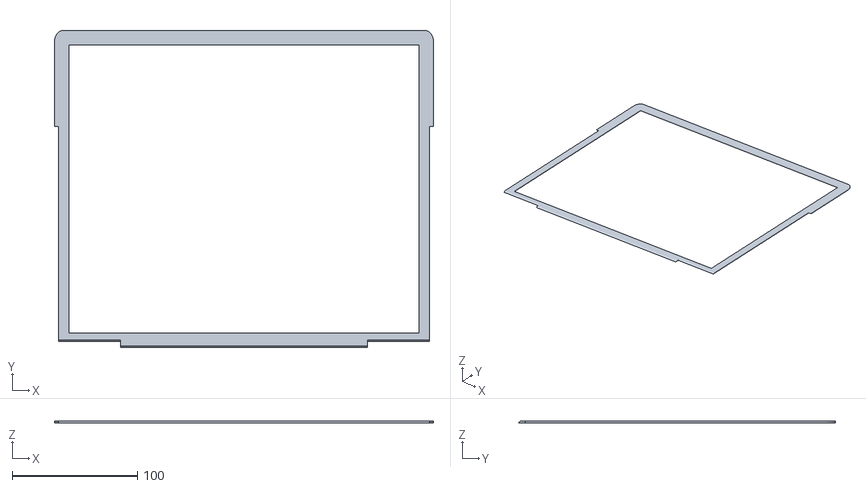
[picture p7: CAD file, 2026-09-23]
teleprompter-stls/Teleprompter_Glass_Holder.stl
302.3 x 252.7 x 1.27

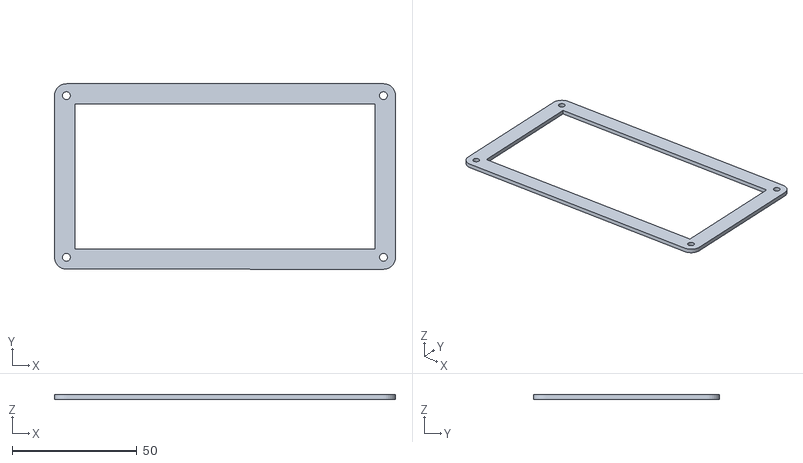
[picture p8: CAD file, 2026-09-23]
teleprompter-stls/Test_Bracket.stl
136.6 x 74.3 x 1.90

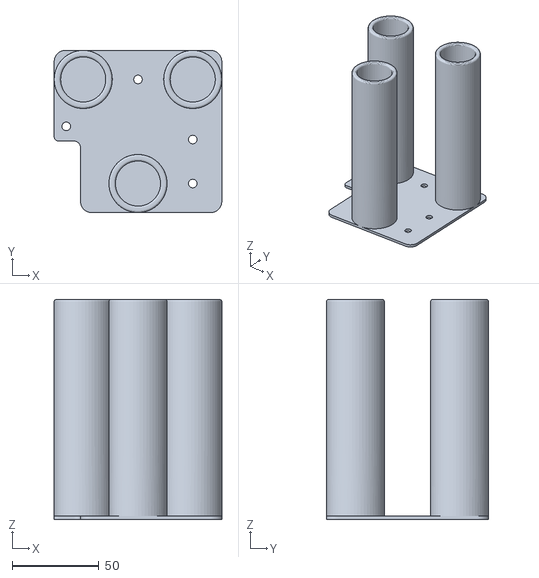
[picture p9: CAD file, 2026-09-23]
teleprompter-stls/Teleprompter_Stand_Top.stl
96.8 x 93.6 x 127.0

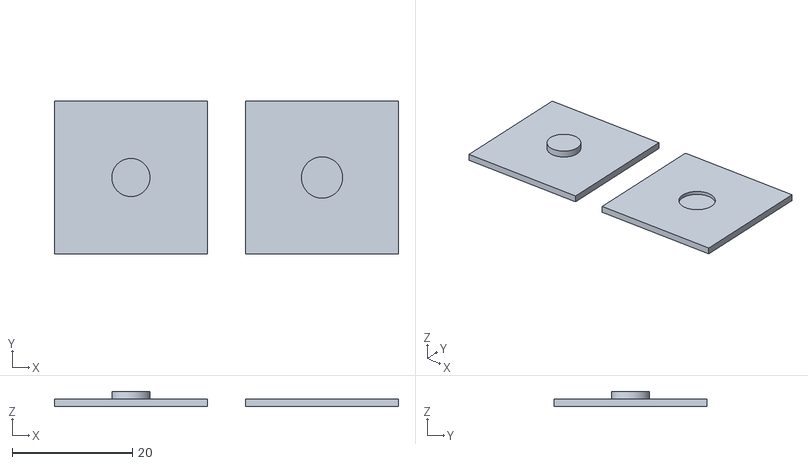
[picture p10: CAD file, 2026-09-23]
teleprompter-stls/Teleprompter_Cloth_Holder.stl
57.2 x 25.4 x 2.54

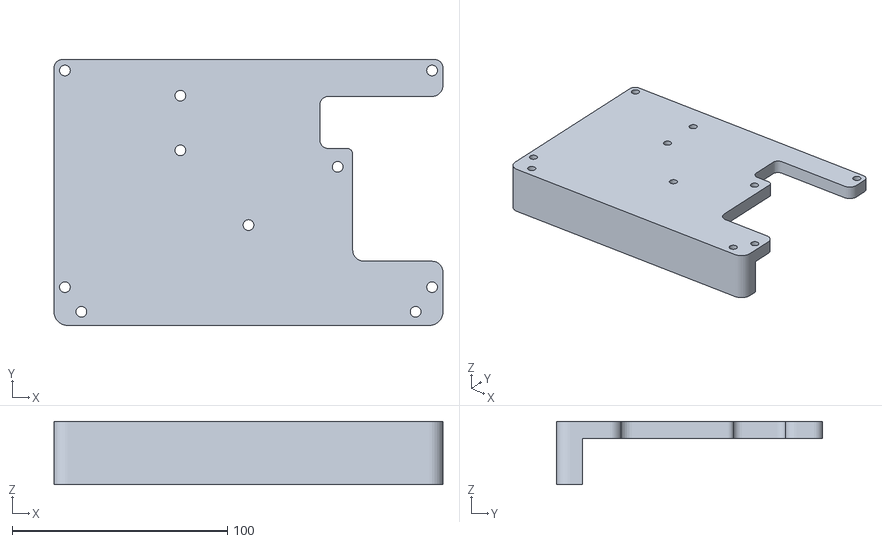
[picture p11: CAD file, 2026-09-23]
teleprompter-stls/Mounting_Bracket.stl
180.6 x 123.5 x 29.4

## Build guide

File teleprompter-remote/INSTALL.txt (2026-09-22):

TELEPROMPTER REMOTE - standalone PlatformIO project
===================================================

This folder is a complete project on its own. It lives in the same repo as
the display firmware, but builds and flashes separately.

1. In VS Code: File > Open Folder, and select THIS folder
   (teleprompter-remote, the one containing platformio.ini).
2. Plug in the remote board only, then Build and Upload.

If the build starts compiling Roboto_96.c or mentions LittleFS or
WebServer, you have the display project open, not this one. This project
has exactly three source files and pulls in no libraries.

Buttons: GPIO7 faster, GPIO5 slower, GPIO4 play/pause. Each one wires
pin -> button -> GND. No resistors. Pins are set in src/ctl_config.h.
See README.md.

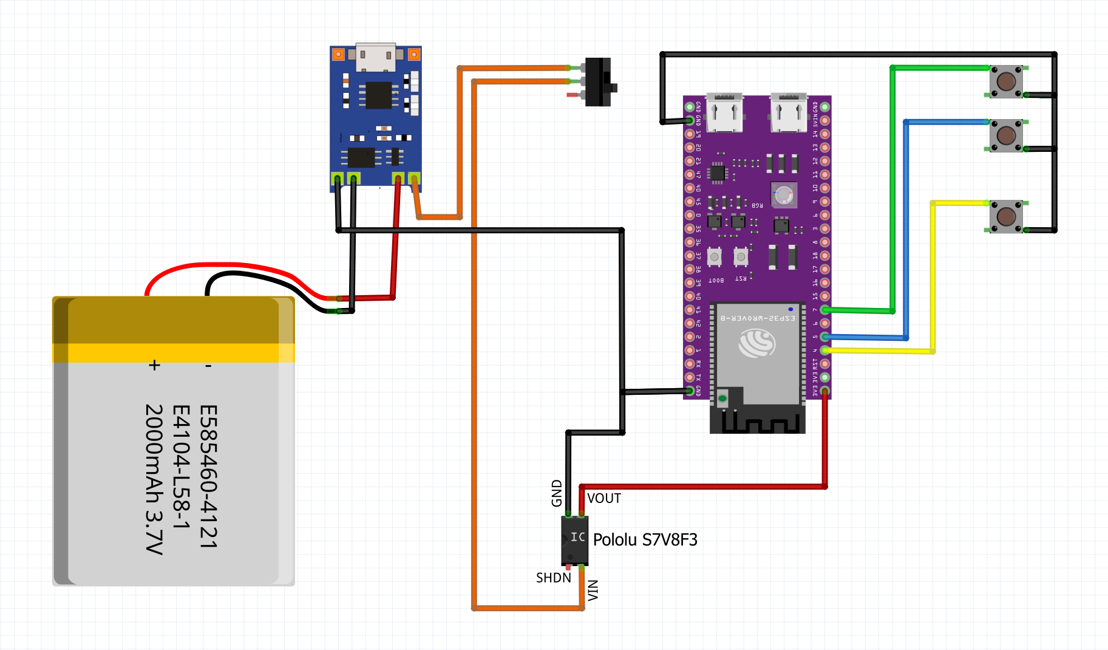
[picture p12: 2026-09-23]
docs/Documentation/remote_wiring_diagram.png

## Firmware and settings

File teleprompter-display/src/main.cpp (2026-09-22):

// Teleprompter for the Waveshare ESP32-S3 7" RGB panel.
//  Original teleprompter design and circuit made by Renn Helm. Code written by Claude Code.
//
// How it stays smooth
// -------------------
// There is no frame buffer and no graphics library in the hot path. The script
// is rasterised once into a rolling 4-bits-per-pixel alpha mask in PSRAM, and
// the RGB peripheral's bounce-buffer callback expands the scanlines it is about
// to shift out straight from that mask through a 256-entry lookup table. The
// work per frame is therefore constant, PSRAM sees almost no traffic, and the
// scroll position advances from the panel's own frame timing, so nothing the
// CPU is busy with - Wi-Fi, HTTP, flash, rasterising the next line - can make
// the text hitch.

#include <Arduino.h>
#include <LittleFS.h>
#include <Preferences.h>
#include <esp_heap_caps.h>
#include <esp_log.h>

#include "tp_app.h"
#include "tp_board.h"
#include "tp_config.h"
#include "tp_display.h"
#include "tp_text.h"
#include "tp_web.h"

static const char *TAG = "teleprompter";

static const char *DEFAULT_SCRIPT =
    "Connect to the Teleprompter Wi-Fi network and open 192.168.4.1 to load "
    "your own script, set the scroll speed, and mirror the text for a "
    "beam-splitter.";

static Preferences s_prefs;

static String s_script;
static float  s_speed      = TP_SPEED_DEFAULT;
static bool   s_mirror     = false;
static int    s_brightness = TP_BRIGHTNESS_DEFAULT;
static int    s_duration_s = TP_DURATION_DEFAULT_S;   // 0 = fixed speed, no target
static float  s_trim       = 0.0f;                   // momentary bias from the remote

static uint32_t s_fps = 0;
static bool     s_prefs_dirty = false;   // speed/brightness settle before hitting flash

// ---------------------------------------------------------------------------
// Pacing
//
// A run is "first line on the reading row" to "last line on the reading row",
// so the distance covered is the height of the script less one line - and it
// does not depend on where the reading row sits. Setting a target length is
// therefore just a division, and it is re-derived whenever the script changes.
// ---------------------------------------------------------------------------

static int32_t run_travel_rows(void)
{
    const int32_t travel = tp_text_rows() - tp_text_line_height();
    return travel > 1 ? travel : 1;
}

// Everything that changes speed goes through here, so the base speed and the
// remote's momentary trim compose instead of fighting over one variable.
static void apply_speed(void)
{
    float v = s_speed * (1.0f + s_trim);
    if (v < TP_PACE_SPEED_MIN) v = TP_PACE_SPEED_MIN;
    if (v > TP_SPEED_MAX) v = TP_SPEED_MAX;
    tp_display_set_speed(v);
}

static void apply_pacing(void)
{
    const int32_t start = -(int32_t)TP_READ_LINE_Y;
    tp_display_set_range(start, start + run_travel_rows());

    if (s_duration_s > 0) {
        float v = (float)run_travel_rows() / (float)s_duration_s;
        if (v < TP_PACE_SPEED_MIN) v = TP_PACE_SPEED_MIN;
        if (v > TP_SPEED_MAX) v = TP_SPEED_MAX;
        s_speed = v;
        ESP_LOGI(TAG, "target %ds over %d rows -> %.1f px/s (%d words, %.0f wpm)",
                 s_duration_s, (int)run_travel_rows(), s_speed,
                 tp_text_word_count(),
                 tp_text_word_count() * 60.0f / (float)s_duration_s);
    }
    apply_speed();
}

// ---------------------------------------------------------------------------
// Persistence
// ---------------------------------------------------------------------------

static String load_script_file(void)
{
    if (LittleFS.exists("/script.txt")) {
        File f = LittleFS.open("/script.txt", "r");
        if (f) {
            String text = f.readString();
            f.close();
            if (text.length()) {
                ESP_LOGI(TAG, "loaded script.txt (%u bytes)", (unsigned)text.length());
                return text;
            }
        }
    }
    ESP_LOGI(TAG, "no script.txt, using the placeholder text");
    return String(DEFAULT_SCRIPT);
}

static bool save_script_file(const String &text)
{
    File f = LittleFS.open("/script.txt", "w");
    if (!f) {
        ESP_LOGE(TAG, "could not open script.txt for writing");
        return false;
    }
    const size_t written = f.print(text);
    f.close();
    if (written != text.length()) {
        ESP_LOGE(TAG, "short write to script.txt (%u of %u)",
                 (unsigned)written, (unsigned)text.length());
        return false;
    }
    return true;
}

// ---------------------------------------------------------------------------
// Re-layout. The display is held blank across this because the mask is being
// rewritten underneath the renderer, and because it covers the flash write.
// ---------------------------------------------------------------------------

static void reload(bool save_to_flash)
{
    tp_display_set_hold(true);
    vTaskDelay(pdMS_TO_TICKS(60));          // let any in-flight scanline retire

    if (save_to_flash) save_script_file(s_script);

    // Rewind first: the render task is still topping the mask up against
    // whatever row the display last reported, and we do not want it chasing a
    // target tens of thousands of rows ahead of a mask we just emptied.
    tp_display_rewind();
    tp_text_set_script(s_script.c_str(), s_script.length(), s_mirror);

    apply_pacing();              // new script length, so re-derive the speed
    tp_display_rewind();         // park on the reading row, run clock at zero
    tp_text_ensure(tp_display_start_row() + TP_LCD_V_RES + TP_LEAD_ROWS, 0);

    tp_display_set_paused(TP_START_PAUSED != 0);
    tp_display_set_hold(false);
}

// ---------------------------------------------------------------------------
// Control surface used by the web UI
// ---------------------------------------------------------------------------

void tp_app_set_script(const String &text)
{
    s_script = text.length() ? text : String(DEFAULT_SCRIPT);
    reload(true);
}

void tp_app_set_speed(float px_per_sec)
{
    if (px_per_sec < TP_SPEED_MIN) px_per_sec = TP_SPEED_MIN;
    if (px_per_sec > TP_SPEED_MAX) px_per_sec = TP_SPEED_MAX;
    s_speed = px_per_sec;
    apply_speed();
    // Deliberately not written straight to NVS: a rotary encoder can produce
    // dozens of these a second, and flash does not enjoy that. loop() flushes.
    s_prefs_dirty = true;
}

// Momentary, and never persisted: a spring-centred control returns to zero and
// the scroll returns to exactly the paced speed.
void tp_app_set_trim(float trim)
{
    if (trim < -TP_TRIM_MAX) trim = -TP_TRIM_MAX;
    if (trim > TP_TRIM_MAX) trim = TP_TRIM_MAX;
    s_trim = trim;
    apply_speed();
}

// Relative, because a fixed px/s step feels completely different at 23 px/s
// than at 200. Floored at the pacing minimum rather than the slider's minimum,
// so a legitimately slow paced speed does not jump when you nudge it.
void tp_app_nudge_speed(float factor)
{
    float v = s_speed * factor;
    if (v < TP_PACE_SPEED_MIN) v = TP_PACE_SPEED_MIN;
    if (v > TP_SPEED_MAX) v = TP_SPEED_MAX;
    s_speed = v;
    apply_speed();
    s_prefs_dirty = true;
}

void tp_app_set_paused(bool paused)
{
    // Pressing play on a finished run means "go again", not "sit at the end".
    if (!paused && tp_display_finished()) tp_app_rewind();
    tp_display_set_paused(paused);
}

void tp_app_set_duration(int seconds)
{
    if (seconds < 0) seconds = 0;
    if (seconds > 4 * 60 * 60) seconds = 4 * 60 * 60;
    s_duration_s = seconds;
    s_prefs.putInt("duration", s_duration_s);
    apply_pacing();
}

// Re-derive the speed from what is actually left, against what is actually
// left of the target. Use mid-run after nudging the speed around.
void tp_app_repace(void)
{
    if (s_duration_s <= 0) return;

    const int32_t remaining_rows = tp_display_end_row() - tp_display_view_row();
    const float remaining_s = (float)s_duration_s - tp_display_run_ms() / 1000.0f;
    if (remaining_rows <= 0 || remaining_s < 1.0f) return;

    float v = (float)remaining_rows / remaining_s;
    if (v < TP_PACE_SPEED_MIN) v = TP_PACE_SPEED_MIN;
    if (v > TP_SPEED_MAX) v = TP_SPEED_MAX;
    s_speed = v;
    s_trim = 0.0f;              // back on schedule means back to neutral
    apply_speed();
    ESP_LOGI(TAG, "re-paced: %d rows in %.1fs -> %.1f px/s",
             (int)remaining_rows, remaining_s, s_speed);
}

void tp_app_set_mirror(bool mirror)
{
    if (mirror == s_mirror) return;
    s_mirror = mirror;
    s_prefs.putBool("mirror", s_mirror);
    reload(false);
}

void tp_app_set_brightness(int percent)
{
    if (percent < 10) percent = 10;
    if (percent > 100) percent = 100;
    s_brightness = percent;
    tp_board_set_brightness((uint8_t)percent);
    s_prefs_dirty = true;
}

void tp_app_rewind(void)
{
    tp_display_set_hold(true);
    vTaskDelay(pdMS_TO_TICKS(40));
    tp_display_rewind();
    tp_text_rewind();
    tp_text_ensure(tp_display_start_row() + TP_LCD_V_RES + TP_LEAD_ROWS, 0);
    tp_display_set_paused(true);      // a rewind means "getting ready for a take"
    tp_display_set_hold(false);
}

const String &tp_app_script(void) { return s_script; }

void tp_app_status(tp_status_t *out)
{
    out->speed          = s_speed;
    out->trim           = s_trim;
    out->paused         = tp_display_paused();
    out->mirror         = s_mirror;
    out->brightness     = s_brightness;
    out->lines          = tp_text_line_count();
    out->words          = tp_text_word_count();
    out->missing_glyphs = tp_text_missing_glyphs();
    out->duration_s     = s_duration_s;
    out->elapsed_ms     = tp_display_run_ms();
    out->finished       = tp_display_finished();
    out->start_row      = tp_display_start_row();
    out->end_row        = tp_display_end_row();
    out->loop_rows      = tp_text_loop_rows();
    out->view_row       = tp_display_view_row();
    out->fps            = s_fps;
    out->free_heap      = (uint32_t)heap_caps_get_free_size(MALLOC_CAP_INTERNAL);
    out->free_psram     = (uint32_t)heap_caps_get_free_size(MALLOC_CAP_SPIRAM);
}

// ---------------------------------------------------------------------------
// Render task: keeps the mask filled ahead of the renderer. In the default
// scanline mode this is all it does - the picture is produced by the panel
// interrupt - so it can stall for a whole second without the scroll noticing.
// ---------------------------------------------------------------------------

static void render_task(void *)
{
    for (;;) {
#if TP_USE_FRAMEBUFFER
        tp_display_render_frame_blocking();
        tp_text_ensure(tp_display_view_row() + TP_LCD_V_RES + TP_LEAD_ROWS,
                       TP_RASTER_BUDGET_ROWS);
#else
        tp_text_ensure(tp_display_view_row() + TP_LCD_V_RES + TP_LEAD_ROWS,
                       TP_RASTER_BUDGET_ROWS);
        vTaskDelay(pdMS_TO_TICKS(20));
#endif
    }
}

// ---------------------------------------------------------------------------

void setup()
{
    Serial.begin(115200);
    esp_log_level_set("*", ESP_LOG_INFO);

    if (!tp_board_init()) {
        ESP_LOGE(TAG, "board init failed - no backlight control, continuing anyway");
    }

    if (!LittleFS.begin(true)) {
        ESP_LOGW(TAG, "LittleFS mount failed even after formatting");
    }
    s_prefs.begin("teleprompt", false);
    s_speed      = s_prefs.getFloat("speed", TP_SPEED_DEFAULT);
    s_mirror     = s_prefs.getBool("mirror", false);
    s_brightness = s_prefs.getInt("bright", TP_BRIGHTNESS_DEFAULT);
    s_duration_s = s_prefs.getInt("duration", TP_DURATION_DEFAULT_S);

    if (!tp_text_init()) {
        ESP_LOGE(TAG, "text engine init failed - halting");
        for (;;) delay(1000);
    }

    s_script = load_script_file();
    tp_text_set_script(s_script.c_str(), s_script.length(), s_mirror);

    // Fill the mask before the panel starts scanning, so the very first frame
    // out of the peripheral already has text in it.
    tp_text_ensure(TP_LCD_V_RES + TP_LEAD_ROWS, 0);

    if (tp_display_init() != ESP_OK) {
        ESP_LOGE(TAG, "display init failed - halting");
        for (;;) delay(1000);
    }

    apply_pacing();                         // run extent, and speed if targeted
    tp_display_rewind();                    // park with line one on the reading row
    tp_display_set_paused(TP_START_PAUSED != 0);

    delay(120);                             // a few good frames before the light
    tp_board_set_brightness((uint8_t)s_brightness);
    tp_board_backlight(true);

    xTaskCreatePinnedToCore(render_task, "tp_render", 4096, nullptr, 4, nullptr, 1);
    tp_web_start();

    if (s_duration_s > 0) {
        ESP_LOGI(TAG, "ready (paused): %d lines, %d words, target %d:%02d at %.1f px/s",
                 tp_text_line_count(), tp_text_word_count(),
                 s_duration_s / 60, s_duration_s % 60, s_speed);
    } else {
        ESP_LOGI(TAG, "ready (paused): %d lines, %d words, %.0f px/s (no target length)",
                 tp_text_line_count(), tp_text_word_count(), s_speed);
    }
}

void loop()
{
    static uint32_t last_frames = 0;
    delay(5000);

    const uint32_t frames = tp_display_frames();
    s_fps = (frames - last_frames) / 5;
    last_frames = frames;

    // Flush settings that the encoder or a slider may have been changing
    // rapidly. NVS only sees a write once the value has settled.
    if (s_prefs_dirty) {
        s_prefs_dirty = false;
        s_prefs.putFloat("speed", s_speed);
        s_prefs.putInt("bright", s_brightness);
    }

#if TP_RENDER_STATS
    ESP_LOGI(TAG, "%u fps | row %d | fill %u/%u us | heap %u | psram %u",
             (unsigned)s_fps, (int)tp_display_view_row(),
             (unsigned)tp_display_take_max_fill_us(), (unsigned)TP_BOUNCE_PERIOD_US,
             (unsigned)heap_caps_get_free_size(MALLOC_CAP_INTERNAL),
             (unsigned)heap_caps_get_free_size(MALLOC_CAP_SPIRAM));
#else
    ESP_LOGI(TAG, "%u fps | row %d | heap %u | psram %u",
             (unsigned)s_fps, (int)tp_display_view_row(),
             (unsigned)heap_caps_get_free_size(MALLOC_CAP_INTERNAL),
             (unsigned)heap_caps_get_free_size(MALLOC_CAP_SPIRAM));
#endif
}

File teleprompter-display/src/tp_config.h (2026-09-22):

// tp_config.h - every tunable for the teleprompter lives here.
#pragma once

#include <stdint.h>

// ---------------------------------------------------------------------------
// Panel: Waveshare ESP32-S3 Touch LCD 7 (1024x600 RGB565)
// ---------------------------------------------------------------------------
#define TP_LCD_H_RES            1024
#define TP_LCD_V_RES            600
#define TP_LCD_PCLK_HZ          (30 * 1000 * 1000)

#define TP_LCD_HSYNC_PULSE      162
#define TP_LCD_HSYNC_BACK       152
#define TP_LCD_HSYNC_FRONT      48
#define TP_LCD_VSYNC_PULSE      45
#define TP_LCD_VSYNC_BACK       13
#define TP_LCD_VSYNC_FRONT      3

#define TP_PIN_VSYNC            3
#define TP_PIN_HSYNC            46
#define TP_PIN_DE               5
#define TP_PIN_PCLK             7
#define TP_PIN_DISP             (-1)

// B3..B7, G2..G7, R3..R7
#define TP_RGB_DATA_PINS        { 14, 38, 18, 17, 10, 39, 0, 45, 48, 47, 21, 1, 2, 42, 41, 40 }

// I2C to the CH422G-style IO expander (backlight, resets)
#define TP_PIN_I2C_SDA          8
#define TP_PIN_I2C_SCL          9
#define TP_I2C_FREQ_HZ          (400 * 1000)
#define TP_IO_EXPANDER_ADDR     0x24
// GPIO4 is the touch controller's INT line. We do not use touch, but the line
// has to be driven low through the vendor's power-up sequence, which is also
// what brings the expander (and the panel rails behind it) into a known state.
#define TP_PIN_TOUCH_INT        4

// ---------------------------------------------------------------------------
// Renderer
// ---------------------------------------------------------------------------
// The scanline renderer generates pixels on the fly into the RGB peripheral's
// bounce buffers, so there is no frame buffer in PSRAM at all. Set this to 1
// only if the no-frame-buffer path misbehaves on your board; it falls back to
// two PSRAM frame buffers, which works but is far slower (see docs/renderer-rewrite.md).
#define TP_USE_FRAMEBUFFER      0

// Lines of pixels generated per bounce-buffer refill. MUST divide TP_LCD_V_RES.
// Legal values for 600: 1,2,3,4,5,6,8,10,12,15,20,24,25,...
// Larger  = more slack against interrupt jitter, more internal RAM.
// Smaller = less internal RAM, tighter real-time deadline.
// 12 lines => 2 x 24 KB of internal RAM, ~550 us of slack per refill.
#define TP_BOUNCE_LINES         12

// How long the panel takes to shift out one bounce buffer, i.e. the deadline
// for generating the next one. Reported alongside the measured fill time in
// the status log when TP_RENDER_STATS is on.
#define TP_LCD_H_TOTAL          (TP_LCD_H_RES + TP_LCD_HSYNC_PULSE + \
                                 TP_LCD_HSYNC_BACK + TP_LCD_HSYNC_FRONT)
#define TP_BOUNCE_PERIOD_US     ((TP_BOUNCE_LINES * TP_LCD_H_TOTAL) / \
                                 (TP_LCD_PCLK_HZ / 1000000))

// Measure scanline generation time and report the worst case every 5s. Cheap,
// and it is the number that matters if the panel ever shows a mistimed band.
#define TP_RENDER_STATS         1

// Foreground / background as 0xRRGGBB.
#define TP_COLOR_FG_DEFAULT     0xFFFFFF
#define TP_COLOR_BG_DEFAULT     0x000000

// ---------------------------------------------------------------------------
// Text
// ---------------------------------------------------------------------------
#define TP_MARGIN_X             48      // left/right padding, px
#define TP_LINE_SPACE           12      // extra px between baselines
#define TP_LETTER_SPACE         0

#define TP_MAX_SCRIPT_BYTES     (64 * 1024)
#define TP_MAX_LINES            4000

// Rolling window of rasterised text held in PSRAM, 4 bits of alpha per pixel.
// MUST be a power of two. 4096 rows x 512 bytes = 2 MB.
#define TP_RING_ROWS            4096
#define TP_MASK_STRIDE          (TP_LCD_H_RES / 2)

// How far ahead of the visible window the rasteriser keeps the ring filled.
#define TP_LEAD_ROWS            1200
// Upper bound on rows rasterised per top-up call, so one call can never
// monopolise the render task.
#define TP_RASTER_BUDGET_ROWS   400
// Blank rows inserted between the end of the script and its restart.
#define TP_GAP_ROWS             TP_LCD_V_RES

// ---------------------------------------------------------------------------
// Scrolling defaults (overridden by whatever is stored in NVS)
// ---------------------------------------------------------------------------
#define TP_SPEED_DEFAULT        74.0f   // px/sec, used when no target length is set
#define TP_SPEED_MIN            2.0f
#define TP_SPEED_MAX            600.0f
#define TP_BRIGHTNESS_DEFAULT   100     // percent, 100 = brightest
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

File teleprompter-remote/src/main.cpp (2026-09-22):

// Teleprompter remote - ESP32-S3, three buttons.
//
// Faster / slower step the display's base speed by a percentage and the change
// sticks, which is what a button wants (unlike a spring-centred control, there
// is nothing to return to neutral on its own). Holding a speed button repeats.
//
// Faster       : +5% per press, repeats when held
// Slower       : -5% per press, repeats when held
// Play         : play / pause
// Play, long   : back to top
// Both speed   : re-pace, recompute the speed to still land on the target time
//
// The LED shows what the display is actually doing, from the status frames it
// sends back: red = no link, amber = paused, green = playing, blue = finished,
// and it blinks when you have drifted more than a few seconds off the target.

#include <Arduino.h>
#include <WiFi.h>
#include <esp_now.h>
#include <esp_wifi.h>

#define TP_REMOTE_BUILD "2026-09-18a"

#include "ctl_config.h"
#include "tp_link.h"

static const uint8_t BROADCAST[6] = { 0xFF, 0xFF, 0xFF, 0xFF, 0xFF, 0xFF };

static uint16_t s_seq = 0;
static uint32_t s_last_tx_ms = 0;
static uint32_t s_flash_until_ms = 0;     // brief LED confirmation of a command

// Link state, updated from the status frames the display sends back
static volatile tp_link_status_t s_status = {};
static volatile uint32_t s_last_status_ms = 0;

// ---------------------------------------------------------------------------
// Link
// ---------------------------------------------------------------------------

static void on_recv(const esp_now_recv_info_t *info, const uint8_t *data, int len)
{
    (void)info;
    if (len != (int)sizeof(tp_link_status_t)) return;

    tp_link_status_t st;
    memcpy(&st, data, sizeof(st));
    if (st.magic != TP_LINK_MAGIC || st.version != TP_LINK_VERSION) return;

    memcpy((void *)&s_status, &st, sizeof(st));
    s_last_status_ms = millis();
}

static void send_cmd(uint8_t cmd, int32_t value)
{
    tp_link_cmd_t m = {};
    m.magic = TP_LINK_MAGIC;
    m.version = TP_LINK_VERSION;
    m.cmd = cmd;
    m.value = value;
    m.seq = ++s_seq;
    const esp_err_t err = esp_now_send(BROADCAST, (const uint8_t *)&m, sizeof(m));

    // Idle pings are not worth printing; everything else is, so "the buttons do
    // nothing" is answerable from the serial monitor alone.
    if (cmd != TP_CMD_PING) {
        static const char *NAMES[] = {
            "ping", "play", "pause", "toggle", "rewind", "speed_delta",
            "speed_set", "repace", "duration", "brightness", "trim", "nudge"
        };
        Serial.printf("tx %-10s value=%ld seq=%u%s\n",
                      cmd < (sizeof(NAMES) / sizeof(NAMES[0])) ? NAMES[cmd] : "?",
                      (long)value, m.seq, err == ESP_OK ? "" : "  SEND FAILED");
    }

    s_last_tx_ms = millis();
    s_flash_until_ms = s_last_tx_ms + 60;
}

static void link_begin(void)
{
    WiFi.mode(WIFI_STA);
    WiFi.disconnect();

    // Force the channel while unassociated. The promiscuous toggle is the
    // belt-and-braces version of this and is harmless.
    esp_wifi_set_promiscuous(true);
    esp_wifi_set_channel(CTL_CHANNEL, WIFI_SECOND_CHAN_NONE);
    esp_wifi_set_promiscuous(false);

    if (esp_now_init() != ESP_OK) {
        Serial.println("esp_now_init failed");
        return;
    }
    esp_now_register_recv_cb(on_recv);

    esp_now_peer_info_t peer = {};
    memcpy(peer.peer_addr, BROADCAST, 6);
    peer.channel = CTL_CHANNEL;
    peer.ifidx = WIFI_IF_STA;
    peer.encrypt = false;
    esp_now_add_peer(&peer);

    Serial.printf("remote up on channel %d, mac %s\n",
                  CTL_CHANNEL, WiFi.macAddress().c_str());
}

// ---------------------------------------------------------------------------
// Buttons. Active low with the internal pull-up.
// ---------------------------------------------------------------------------

enum : uint8_t { EV_NONE = 0, EV_PRESS, EV_REPEAT, EV_LONG, EV_SHORT_RELEASE };

struct button_t {
    uint8_t  pin;
    bool     stable;            // true = released
    bool     last_raw;
    uint32_t changed_ms;
    uint32_t pressed_ms;
    uint32_t next_repeat_ms;
    bool     long_fired;
    bool     suppressed;        // consumed by a chord, ignore until released
};

static button_t s_faster = { CTL_PIN_FASTER, true, true, 0, 0, 0, false, false };
static button_t s_slower = { CTL_PIN_SLOWER, true, true, 0, 0, 0, false, false };
static button_t s_play   = { CTL_PIN_PLAY,   true, true, 0, 0, 0, false, false };

static bool held(const button_t &b) { return !b.stable; }

static uint8_t service_button(button_t &b, bool repeats, bool wants_long)
{
    const bool raw = digitalRead(b.pin);
    const uint32_t now = millis();

    if (raw != b.last_raw) {
        b.last_raw = raw;
        b.changed_ms = now;
    }

    uint8_t event = EV_NONE;

    if ((now - b.changed_ms) >= CTL_DEBOUNCE_MS && raw != b.stable) {
        b.stable = raw;
        Serial.printf("btn GPIO%u %s\n", (unsigned)b.pin, raw ? "up" : "DOWN");
        if (!raw) {                         // pressed
            b.pressed_ms = now;
            b.next_repeat_ms = now + CTL_REPEAT_DELAY_MS;
            b.long_fired = false;
            b.suppressed = false;
            event = EV_PRESS;
        } else {                            // released
            if (b.suppressed) { b.suppressed = false; }
            else if (!b.long_fired) event = EV_SHORT_RELEASE;
        }
    }

    if (b.suppressed) return EV_NONE;

    if (repeats && held(b) && now >= b.next_repeat_ms) {
        b.next_repeat_ms = now + CTL_REPEAT_MS;
        event = EV_REPEAT;
    }

    if (wants_long && held(b) && !b.long_fired &&
        (now - b.pressed_ms) >= CTL_LONG_PRESS_MS) {
        b.long_fired = true;
        event = EV_LONG;
    }

    return event;
}

// ---------------------------------------------------------------------------
// LED
// ---------------------------------------------------------------------------

static void led_show(uint8_t r, uint8_t g, uint8_t b)
{
#if CTL_PIN_LED >= 0
    // Only write on an actual change. Re-sending the same colour 25 times a
    // second is pointless, and with CORE_DEBUG_LEVEL=3 every call also printed
    // a deprecation warning, which buried the serial log.
    static int last_r = -1, last_g = -1, last_b = -1;
    if (r == last_r && g == last_g && b == last_b) return;
    last_r = r; last_g = g; last_b = b;
    rgbLedWrite(CTL_PIN_LED, r, g, b);
#else
    (void)r; (void)g; (void)b;
#endif
}
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

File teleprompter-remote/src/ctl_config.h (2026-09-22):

// ctl_config.h - everything you might rewire or retune on the remote.
#pragma once

// ---------------------------------------------------------------------------
// Pins (ESP32-S3-N16R8 DevKitC)
//
// All three buttons wire to GND with the internal pull-up enabled, so each one
// is two wires and nothing else. No ADC involved, so none of the ADC1-only
// restriction that a joystick would have imposed.
//
// Avoided: 0/45/46 (strapping), 19/20 (USB), 26-32 (flash) and 33-37 (the
// octal PSRAM on an N16R8 part).
// ---------------------------------------------------------------------------
#define CTL_PIN_FASTER          7
#define CTL_PIN_SLOWER          5
#define CTL_PIN_PLAY            4 

// Onboard addressable LED on most S3 DevKitC boards. Set to -1 if yours has
// none, or change the pin if it differs.
#define CTL_PIN_LED             48

// ---------------------------------------------------------------------------
// Link. Must match the display's tp_config.h.
// ---------------------------------------------------------------------------
#define CTL_CHANNEL             1

// ---------------------------------------------------------------------------
// Speed steps
// ---------------------------------------------------------------------------
// Per press, as a fraction. Relative rather than a fixed px/s, because a
// "+5 px/s" step would be a 22% change at 23 px/s and a 2% change at 200 px/s.
// A percentage feels the same whatever the script length.
#define CTL_STEP                0.05f

// Hold a speed button to repeat. Roughly 6 steps a second once it gets going,
// so about a second of holding is a 1.34x change.
#define CTL_REPEAT_DELAY_MS     500
#define CTL_REPEAT_MS           150

// ---------------------------------------------------------------------------
// Timing
// ---------------------------------------------------------------------------
#define CTL_POLL_MS             15
#define CTL_DEBOUNCE_MS         25
#define CTL_LONG_PRESS_MS       800     // play button long press = back to top
#define CTL_HEARTBEAT_MS        1000    // so the display knows where to reply
#define CTL_LINK_LOST_MS        2500    // no status for this long = show red
